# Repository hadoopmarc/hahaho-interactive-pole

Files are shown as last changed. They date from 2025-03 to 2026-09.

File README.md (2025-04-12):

# Hahaho Interactive Pole
The Interactive Pole is a standalone fun device that can be positioned in supervisioned public spaces. It features an activation button, various sensors, loudspeakers and several lighting and display options. The pole as displayed below originated from a project for the Amsterdam Police, carried out by one of the members of the Hahaho Foundation. 



The joined membership of the Hahaho Foundation feels that the remaining prototypes can serve for applications with a higher fun factor and we will use the interactive pole as a project in which people of all skill-levels can participate. If you live near Utrecht and want to see the pole in action, check our [website](https://hahaho-makers.nl/) for our biweekly meetings.

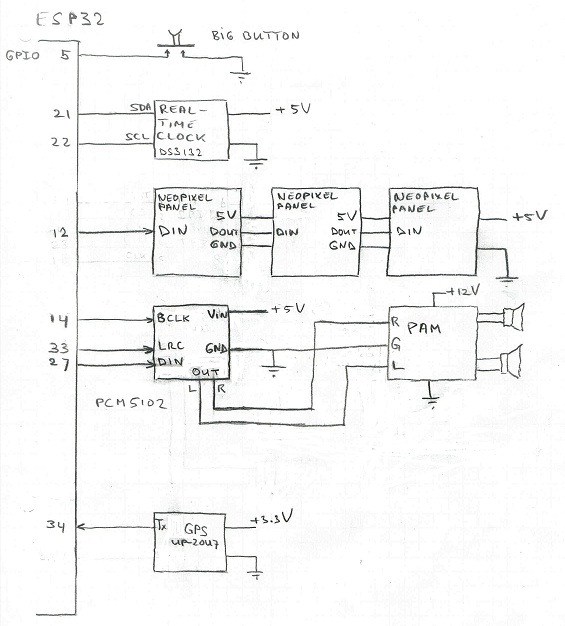
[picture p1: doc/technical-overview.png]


The figure above provides a schematic overview of the entire system (from the [detailed documentation](https://github.com/hadoopmarc/hahaho-interactive-pole/blob/main/inspiration/doc/HIP.pdf)). The table below shows the connections between the various components and the ESP32 dev board.

```c
//***************************************************************************************************
// Wiring.                                                                                          *
// ------------------------------------------------------------------------------------------------ *
// ESP32dev Signal  Connected to                Remarks                                             *
// -------- ------  --------------              ----------------------------------------------      *
// GPIO0    BOOT    Reserved bootloader         Also 2nd start button for test                      *
// GPIO1    TXD0    Reserved serial output                                                          *
// GPIO2            Built-in LED                                                                    *
// GPI03    RXD0    Reserved serial input                                                           *
// GPIO4            -                                                                               *
// GPIO5            Big button                  (active low)                                        *
// GPIO12           Neopixel panel DIN                                                              *
// GPIO14           I2S BCLK naar bijv. MAX98357A / PCM5102                                         *
// GPIO15           -                                                                               *
// GPIO16   RXD2    -                                                                               *
// GPIO17   TXD2    -                                                                               *
// GPIO18   SCK     -                                                                               *
// GPIO19   MISO    -                                                                               *
// GPIO21           SDA for I2C (DS3132)                                                            *
// GPIO22           SCK for I2C (DS3132)                                                            *
// GPIO23   MOSI    -                                                                               *
// GPIO25   -       audio output van interne DAC.                                                   *
// GPIO26   -       audio output van interne DAC.                                                   *
// GPIO27   -       I2S DIN  naar bijv. MAX98357A / PCM5102                                         *
// GPIO32   -       Enable VIN of PCM5102                                                           *
// GPIO33   -       I2S LRC  naar bijv. MAX98357A / PCM5102                                         *
// GPIO34   -       GPS TX                      (input only pin)                                    *
// GPIO35   -       -                           (input only pin)                                    *
// -------  ------  ----------------                                                                *
// GND      -       Power supply GND                                                                *
// VCC 5 V  -       Power supply                                                                    *
// VCC 5 V  -       Power supply                                                                    *
// 3.3 V    -       GPS Vcc                                                                         *
// EN       -       -                                                                               *
//***************************************************************************************************
```

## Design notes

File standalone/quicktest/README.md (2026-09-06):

## Intereractive Pole Quicktest

This is a useful small script that demonstrates the functionality of the Interactive Pole as of August 2026. Herman composed it using AI. These are the functionalities demonstrated:

 - sensing of the red button being pushed
 - sensing of passing people using the two PIR sensors
 - playing a sound file with the mp3-player
 - displaying a text on the Neopixel display
 - flashing the stroboscope light
 
 The functionalities it misses compared to the full firmware:
 
 - webserver with dashboard, serial monitor and OTA-updates
 - high level library to program the Interactive Pole without detailed knowledge of the sensors and actuators

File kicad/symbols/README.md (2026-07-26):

https://forum.kicad.info/t/esp32-dev-ch340-c-symbol-and-footprint/56483/13

See for elegant way to install 3rd party symbols and footprints: https://github.com/hadoopmarc/gps-controlled-lcd-shutter/blob/main/kicad/footprints/README.md

Something similar in win11 can be configured in:
C:\Users\marcd\Documents\KiCad\10.0\3rdparty
So, just put the .kicad_sym and .kicad_mod files in this directory.

Note that the system libraries are located at (after installing for all users):
C:\Program Files\KiCad\10.0\share\kicad

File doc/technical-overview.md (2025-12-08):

#technisch overzicht

Electronic parts
- ESP-WROOM-32
- [PCM5102A DAC module for Raspberry Pi](https://manuals.plus/asin/B07Q9K5MT8, also see for soldering bridges: https://github.com/pschatzmann/arduino-audio-tools/wiki/External-DAC)
- [PAM8610 2x15 W audio amplifier](https://nl.aliexpress.com/item/1005006493004179.html)
- 2 x loudspeaker 5W
- microswitch
- microphone
- [2 x HC-SR501 PIR sensor module](https://nl.aliexpress.com/item/1005006834678128.html or https://nl.aliexpress.com/item/1005006227628663.html)
- (GPS module Ublox Neo 6M)
- PCB, including 12V to 5V power supply
- 12V accu

Hardware parts:
- pole
- stand
- large button

Future actuators:
- LED's
- displays

Future sensors:
- lidar

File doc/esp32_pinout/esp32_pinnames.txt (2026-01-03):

The pinnames below are defined in src/libraries/h3ip_wiring/esp32_wiring.h

They are repeated below to allow for copy/paste to the pinout diagram.

Left column

reserved
ADC1_0
ADC1_3
frontPIR
backPIR
bclkI2S
lrcI2S
DAC1
DAC2
dinI2S
sckHSPI
misoHSPI
mosiHSPI

Right column

free
sclI2C
reserved
reserved
sdaI2C
stroboscope
neoPixel
redButton
mp3DFTX
mp3DFRX
buzzer
internalLED
csHSPI

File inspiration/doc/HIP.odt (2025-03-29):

HaHaHo Interactive Pole

# Inleiding.

Dit document beschrijft de ontwikkeling van de voorganger van de HaHaHo Interactive Pole. Het gaat hierbij om een paal met daarin een microprocessor.

# Hardware.

De hardware bestaat uit de paal met daarop een grote knop (type noodstop). In de paal bevindt zich een ESP32 processor, een versterker, een luidspreker waarop teksten kunnen worden uitgestuurd, twee Neopixel displays (voorzijde en achterzijde) met elk 4 panels van 8x8 Neopixels, een Real time clock en een GPS module.
De elektronica wordt gevoed vanuit een (oplaadbare) accu.

# Software.

De software voor de ESP32 is geschreven in C++. PlatformIO wordt gebruikt als ontwikkelsysteem.
De broncode van de software is vrij toegankelijk.
De software kan geconfigureerd worden d.m.v. een geïntegreerde webinterface. Via de webinterface is er toegang tot de loggegevens. De gegevens op het display zijn ook zichtbaar via de webinterface.

# User interfaces.

Op de voorkant van de paal is een display aanwezig. Er is gekozen voor 4 Neopixel panels van 65 x 65 mm. Deze is zichtbaar voor de passanten. Aan de achterzijde is ook een paneel voor de beambte. Hierop wordt het volgnummer gepresenteerd.

Na opstarten is het systeem gereed en kan het gebruikt worden. De GPS coördinaten van de plaats van de paal wordt gemeten indien er signaal van voldoende satellieten ontvangen kan worden. Zodra de coördinaten bekend zijn wordt dat getoond op de “home”-pagina van de webinterface.
De coördinaten worden opgeslagen in de registratie-file.

Bij opstarten toont het display in blauwe cijfers het IP-adres, waarmee toegang tot de webinterface kan worden verkregen. Dit gaat in 4 stappen, bijvoorbeeld “192”, “168”, “4”, “1”. In dit voorbeeld is het IP-adres 192.168.4.1.

In ruststand wordt op het display een patroon getoond om aan te geven dat de volgende passant geaccepteerd kan worden. Zodra er dan op de grote knop wordt gedrukt wordt krijgt de passant een reactie. Op het paneel aan de de achterzijde wordt het volgnummer getoond in rood of groen.
Tegelijkertijd klinkt uit de luidspreker in de paal de tekst zoals: “Spring drie keer in de lucht” of “Loop een rondje rond de paal”, al of niet voorafgegaan door het volgnummer. De gesproken teksten zijn beschikbaar in 2 talen (Nederlands en Engels). Er kan ingesteld worden welke taal of talen worden gebruikt en of het volgnummer al dan niet moet worden uitgesproken.

De gegevens van de passerende personen worden opgeslagen (alleen volgnummer en tijdstip) in registratiefiles. Om de hoeveelheid data te beperken worden de niet-geselecteerde personen niet geregistreerd. Dat zijn dus de ontbrekende volgnummers.

Er is een tweede user-interface beschikbaar via een WiFi verbinding. Daartoe wordt er op de ESP32 een AP (accesspoint) aangemaakt waarop kan worden ingelogd met een PC, tablet of telefoon. De naam van het accesspoint is “HIP-NET-xx”, waarbij “xx” een code is die bepaald wordt door het MAC adres van de ESP32. Dit maakt het mogelijk om met meer dan één paal vlak bij elkaar te werken. Het IP-adres wordt getoond bij opstarten van de ESP32. Ga met een willekeurige browser naar http://<IP-adres>/index.html.

# Webinterface.

## Hoofdscherm (Home).

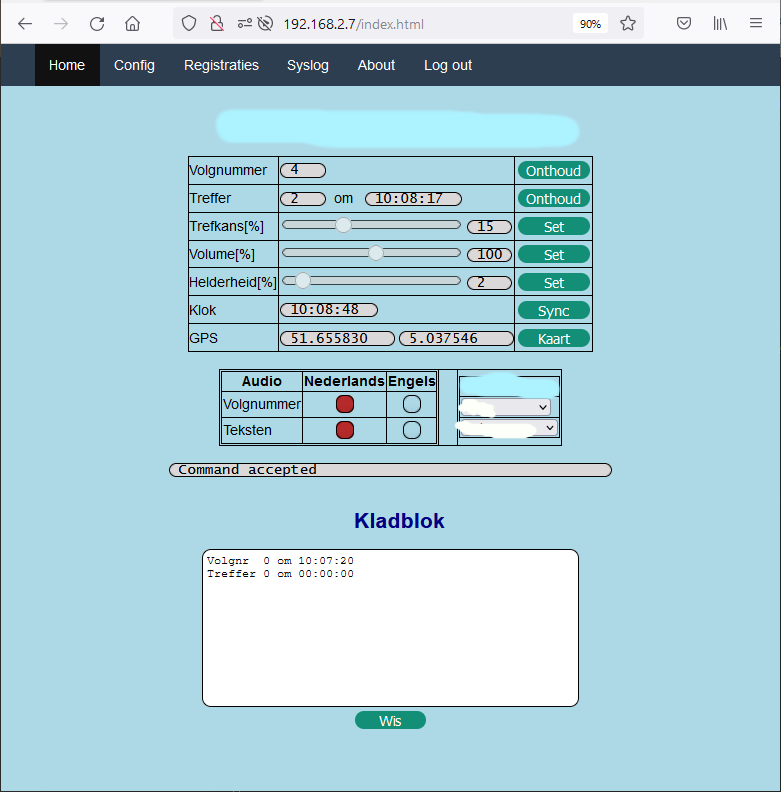
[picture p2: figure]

Het hoofdscherm toont het volgnummer en het nummer van de laatste “treffer”. Met de “Onthoud” knoppen kan een geheugensteuntje (volgnummer of treffer) in het kladblok onderaan het scherm worden gezet. De trefkans kan worden ingesteld met de schuifbalk, daarna op “Set” klikken. Op dezelfde manier kan het volume van de luidspreker en de helderheid van het display ingesteld worden met de daarbij behorende schuifbalken
De RTC clock kan worden gelijkgezet met de klok van de aangesloten PC/tablet/telefoon.
De GPS-regel toont de coördinaten van de huidige positie van de paal. Het kan even duren voordat er voldoende satellieten gedetecteerd zijn. Soms is dat onmogelijk en blijven de coördinaten leeg.

Met de knoppen in het “Audio”-blokje is te configureren welke teksten worden uitgesproken.

Met de “Kaart”-knop wordt die positie op een kaart aangegeven (indien er Internet verbinding is).

Verder kunnen de audio-instellingen worden gewijzigd en het model van de signalering (pijl of stoplicht). Omdat bij het pijl-model de uitgang voor niet geselecteerde mensen soms rechts en soms links is, kan links en rechts worden omgewisseld. Kies voor “Rechts uit” of “Links uit”.

## Configuratiescherm (Config).

Hierin kunnen wat configuratie parameters opgeslagen worden. Het scherm is alleen toegankelijk voor de “admin” user.
Het scherm ziet er als volgt uit:

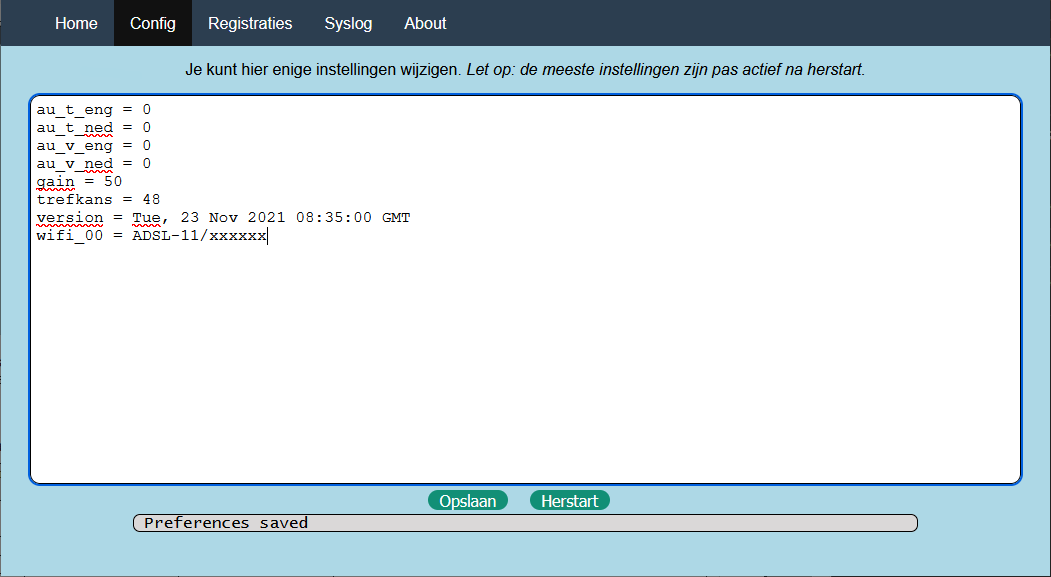
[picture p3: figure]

Na het aanpassen van de mogelijke instellingen moet er op “Opslaan” worden gedrukt. De instellingen hebben veelal pas effect na een herstart, daarom is er ook een “Herstart” -knop aanwezig.

### Configuratie parameters.

De volgende parameters kunnen worden ingesteld in het configuratiescherm.

Parameter naam | Voorbeeld parameter | Default | Beschrijving
trefkans | 50 | 20 | Trefkans in procenten. 20 procent is een kans van 1 op 5.
userpw | H7Ft20? | bloemkool | Het password voor normale toegang.
adminpw | BLT66.. | supernova | Het password voor admin user met extra rechten.
wifipw | hkp32x4 | Gelijk aan netwerk naam. | Het password voor de WiFi verbinding. Bijvboorbeeld “VGW-NET-CE”.
au_v_ned | 0 | 1 | Audio aan/uit voor Nederlands volgnummer.
au_t_ned | 0 | 1 | Audio aan/uit voor Nederlandse tekst.
au_v_eng | 0 | 1 | Audio aan/uit voor Engels volgnummer.
au_t_eng | 0 | 1 | Audio aan/uit voor Engelse tekst.
gain | 66 | 50 | Audio output niveau 0..100 procent
wifi_00 | ZIGGO_V22/passwd | | WiFi netwerk en password voor “station”-toegang.
wifi_01 | ZIGGO_V33/passwd | | Tweede WiFi netwerk en password voor “station”-toegang.
brightness | 20 | 30 | Helderheid Neopixel panels 0..255.
model | Matrix image | pijl | Display model 1
lrrev | Matrix image | rechts | Display model 2

De groen gekleurde parameters zijn ook via de home page van de web interface instelbaar.

De WiFi instellingen zijn vooral handig tijdens het ontwikkelen en testen van de software. Je kunt dan via het WiFi accesspoint van het interne WiFi net toegang krijgen tot de ESP32. Bij een reset wordt namelijk het interne WiFi accesspoint van de ESP32 uitgeschakeld, waardoor je steeds opnieuw moet inloggen op het accesspoint.

De 2 passwords moeten zo snel mogelijk aangepast worden.

Indien toegang niet meer mogelijk is, dan is een reset van de 3 passwords mogelijk door tijdens het opstarten (terwijl het IP-adres getoond wordt) de grote knop continue in te drukken. Daarna wachten tot het systeem gereed is (de pijlen worden getoond), dan opnieuw opstarten zonder op de knop te drukken.
Vergeet niet de passwords weer in te stellen.

## Registratiescherm.

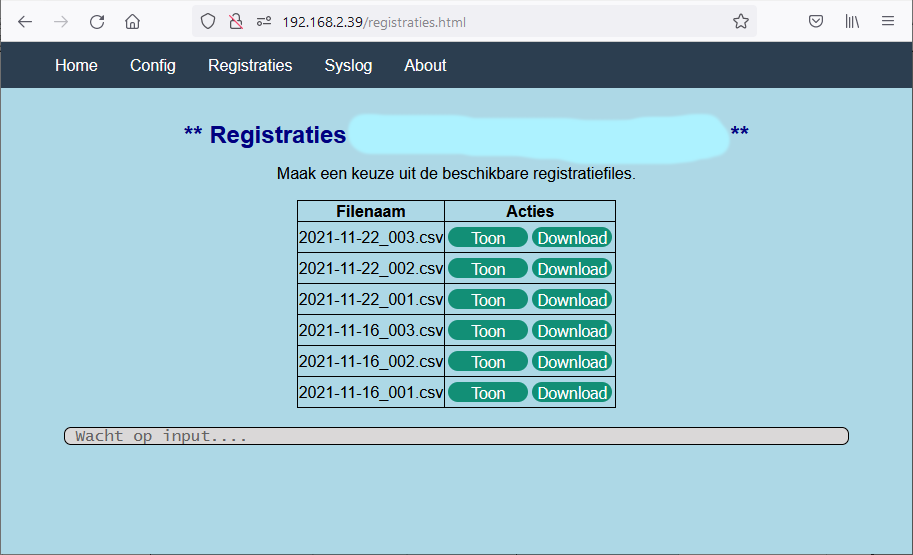
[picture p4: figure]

Alle in het filesysteem aanwezige registratiefiles worden getoond. De laatste aangemaakte registratiefile staat bovenaan. Met de “Toon” knop kan deze worden ingezien. Met de “Download” knop kan de betreffende file opgeslagen worden of direct geopend worden in bijvoorbeeld Excel.

Een beschrijving van de registratiefiles staat in hoofdstuk 7.

## Syslogscherm.

Dit scherm toont debug informatie Het wordt alleen gebruikt tijden ontwikkelen en testen van de software. Het scherm is alleen toegankelijk voor de “admin”-user.

## Aboutscherm.

Dit scherm geeft wat info over het systeem.

# Schematisch overzicht.


//***************************************************************************************************

// Wiring. *

// ------------------------------------------------------------------------------------------------ *

// ESP32dev Signal Connected to Remarks *

// -------- ------ -------------- ---------------------------------------------- *

// GPIO0 BOOT Reserved bootloader Also 2nd start button for test *

// GPIO1 TXD0 Reserved serial output *

// GPIO2 Built-in LED *

// GPI03 RXD0 Reserved serial input *

// GPIO4 - *

// GPIO5 Big button (active low) *

// GPIO12 Neopixel panel DIN *

// GPIO14 I2S BCLK naar bijv. MAX98357A / PCM5102 *

// GPIO15 - *

// GPIO16 RXD2 - *

// GPIO17 TXD2 - *

// GPIO18 SCK - *

// GPIO19 MISO - *

// GPIO21 SDA for I2C (DS3132) *

// GPIO22 SCK for I2C (DS3132) *

// GPIO23 MOSI - *

// GPIO25 - audio output van interne DAC. *

// GPIO26 - audio output van interne DAC. *

// GPIO27 - I2S DIN naar bijv. MAX98357A / PCM5102 *

// GPIO32 - Enable VIN of PCM5102 *

// GPIO33 - I2S LRC naar bijv. MAX98357A / PCM5102 *

// GPIO34 - GPS TX (input only pin) *

// GPIO35 - - (input only pin) *

// ------- ------ ---------------- *

// GND - Power supply GND *

// VCC 5 V - Power supply *

// VCC 5 V - Power supply *

// 3.3 V - GPS Vcc *

// EN - - *

//***************************************************************************************************

# Registratiefiles.

Als er na een druk op de knop een selectie heeft plaatsgevonden, dan wordt dat geregistreerd in een file. De registratiefiles worden opgeslagen in het flash-geheugen van de ESP32 in de SPIFFS partitie. De naam van een registratiefile ziet er bijvoorbeeld zo uit:

2021-11-01_001.csv

Het eerste gedeelte van de filenaam is de datum van aanmaak in de vorm “YYYY-MM-DD”. Het tweede gedeelte is een volgnummer voor het geval er meer dan één file op de dag aangemaakt wordt.
Als er te weinig ruimte aanwezig is in het filesysteem, dan worden de oudste files verwijderd.

## Registratiefile structuur.

Een registratiefile bestaat uit een aantal records. Records worden van elkaar gescheiden door een newline. Velden in een record worden van elkaar gescheiden door een komma. Een registratiefile is hiermee geschikt om ingelezen te worden in bijvoorbeeld Excel.

Er zijn 3 record types:

Type | Omschrijving
P | Ingestelde trefkans in procent (probability).
G | GPS locatie. Bevat datum (DD-MM-JJJJ) en de GPS coördinaten.
H | Volgnummer en tijdstip van een geselecteerde persoon.

Het “G” record komt slechts één keer voor aan het begin van de file.
Het “P” record staat ook altijd aan het begin. Indien de trefkans wordt gewijzigd volgt er een extra “P”-record.

Voorbeeld van de inhoud van een registratiefile:

G,01-11-2021,51.655863,5.037566

P,50

H,6,17:25:34

H,7,17:26:07

H,9,17:26:13

H,10,17:30:51

H,11,17:30:53

H,17,17:31:02

H,18,17:31:13

H,19,17:31:15

H,22,17:31:19

H,25,17:31:24

H,27,17:31:32

…

Er werd hier dus gewerkt op 1 november 2021 op locatie 51.655863, 5.037566 met een trefkans van 50 procent. De eerste selectie was om 17:25:34.

# Characterset 8x8 display.

Op de 8x8 Neopixel displays kan een beperkt aantal tekens worden weergegeven.
Dat zijn de cijfers 0 t/m 9, een “V”, een “X”, een “>” en een “<”. De vormgeving is als volgt:

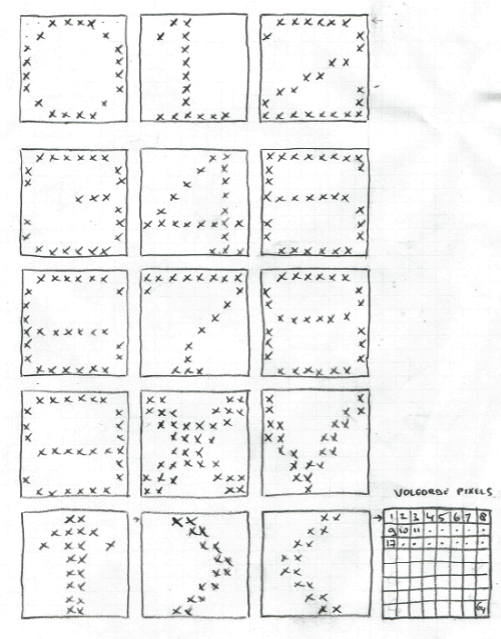
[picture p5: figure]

Het eerste pixel p het paneel is linksboven, volgende pixel is degene daar rechts van. Dan rij afmaken en dan naar de volgende rijen. Dus van links naar rechts en van boven naar beneden. Dit geldt voor de 66 x 66 mm modules.

De tekens worden weergegeven op 4 panelen, verticaal. Elk teken wordt gevolgd door 2 onverlichte rijen. Voor de pijl naar beneden en de drukknop zijn speciale tekens gemaakt.

HIP -- pagina 7

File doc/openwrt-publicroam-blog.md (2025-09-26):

# A Raspberry Pi travel router for publicroam.nl

The [Makey Mondays in Utrecht](https://www.meetup.com/hahaho-sharingtechnology-innovative-tech-meetings/events/?type=past),
The Netherlands, have a special requirement
on the use of the [publicroam.nl](https://publicroam.nl/en/) Wi-Fi network.
Participants should be able to connect to the internet through publicroam.nl and at
the same time be able to perform OTA (over the air) firmware upgrades to simple
microcontrollers like the
[ESP32](https://www.espressif.com/en/products/socs/esp32). However, it is not easy to
make such microcontrollers connect with publicroam.nl, because it requires
authentication with the
[PEAP/EAP-MSCHAPV2 protocol](https://en.wikipedia.org/wiki/Protected_Extensible_Authentication_Protocol). This
protocol on its turn requires several libraries that take a lot of
the scarce resources of a simple microcontroller. Therefore, it is more
attractive to use an additional wireless router that connects to publicroam.nl and
serves as a simple secure Wi-Fi access point with a second radio, see
the figure below. This blog post details how this was realized using an old
[Raspberry Pi](https://www.raspberrypi.com/) configured with
[OpenWrt](https://openwrt.org/) routing firmware.

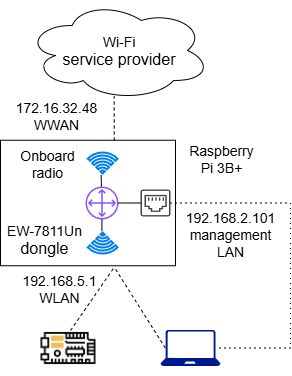
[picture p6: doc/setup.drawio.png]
Connection diagram


It can be noted that this setup is identical to that of a travel router, which is
often used to act as a protective shield when using untrusted hotel Wi-Fi networks.
In fact, OpenWRT has the `Travelmate` extension package to easily make available
known configurations to public Wi-Fi service providers. However, the publicroam.nl
configuration does not seem to easily fit in this framework, as I could not find
any references to it. Therefore, the exploration towards the proper configuration
for publicroam.nl was done without `Travelmate`.

Looking back, the main hurdle encountered was to give the OpenWrt `wpad` package
access to the [publicroam.nl certificate](https://publicroam.nl/certificate-latest)
for the IEEE 802.1x authentication that is part of the MSCHAPV2 protocol. The [LuCI
webui](https://openwrt.org/docs/guide-user/luci/start) to OpenWrt suggests that
uploading the certificate with LuCI should suffice, but this turned out to fail.
This was followed by a number of random attempts with different versions of the
`wpad` package and different ways to install the certificate, until I hit upon
a working configuration. Because of my limited knowledge of OpenWrt, linux and
certificate chains, I have not tried to simplify the resulting configuration or
pinpoint any issues in OpenWrt. I figured, though, that the literal documentation
of the resulting configuration could be of help to other users and here it is!

Without detailing steps documented elsewhere, the setup described can be
realized as follows:
- be sure that you use a solid 5V/3A power supply for the RPi, because the power
drawn by an additional radio can easily result in brownout situations (RPi gets
in a reboot loop). To be on the safe side, radio transmit power in the configurations
below is limited to 10 mW
- burn the OpenWrt firmware on the RPi's SD-card as described
[here](https://openwrt.org/toh/raspberry_pi_foundation/raspberry_pi)
- get [SSH access to OpenWrt](https://openwrt.org/docs/guide-quick-start/sshadministration)
from your laptop
- using LuCI temporarily connect to your private Wi-Fi network for internet access
- using LuCI install the following OpenWrt pacakages: ca-bundle, kmod-rtl8192cu,
openssh-sftp-server, openssl-util, rtl8192cu-firmware, wpa-cli, wpad-openssl
- insert a Wi-Fi USB dongle as a second radio (the rtl8192cu packages installed
above are required for the prevalent EW-7811Un dongle)
- copy the config files detailed below to /etc/config, e.g. using winscp (after
editing credentials and network names)
- copy the downloaded
[publicroam Wi-Fi certificate](https://publicroam.nl/certificate-latest) to /etc/ssl/certs
- get a terminal in the RPi with ssh or Putty and run the command `openssl rehash`
- reboot the RPi and you should be able to connect to the configured SSID using
the configured password. In a publicroam environment the system logs in LuCI should
indicate a valid connection to publicroam (see the end of this post for example
logs).

Hardware: Raspberry Pi 3B+ with EW-7811Un from Edimax \
Firmware: openwrt-24.10.2-bcm27xx-bcm2710-rpi-3-squashfs-sysupgrade.img.gz

/etc/config/network
```
config interface 'loopback'
	option device 'lo'
	option proto 'static'
	option ipaddr '127.0.0.1'
	option netmask '255.0.0.0'

config device
	option name 'br-lan'
	option type 'bridge'
	list ports 'eth0'

config interface 'lan'
	option device 'br-lan'
	option proto 'dhcp'

config interface 'wlan_hahaho'
	option proto 'static'
	option ipaddr '192.168.5.1'
	option netmask '255.255.255.0'
	option device 'phy0-ap0'

config interface 'wwan_pubroam'
	option proto 'dhcp'
	option device 'radio0.network1'
```
 /etc/config/wireless
```
config wifi-device 'radio0'
	option type 'mac80211'
	option path 'platform/soc/3f300000.mmcnr/mmc_host/mmc1/mmc1:0001/mmc1:0001:1'
	option channel 'auto'
	option band '5g'
	option htmode 'VHT20'
	option cell_density '0'
	option log_level '0'
	option txpower '10'

config wifi-iface 'default_radio0'
	option device 'radio0'
	option mode 'sta'
	option encryption 'wpa2'
	option network 'wwan_pubroam'
	option ssid 'publicroam'
	option log_level '0'
	option eap_type 'peap'
	option auth 'EAP-MSCHAPV2'
	option identity 'publicroam-username'
	option password 'publicroam-password'
	option anonymous_identity 'anonymous'
	option ieee80211w '1'
	option ca_cert_usesystem '1'

config wifi-device 'radio1'
	option type 'mac80211'
	option path 'platform/soc/3f980000.usb/usb1/1-1/1-1.2/1-1.2:1.0'
	option channel '9'
	option band '2g'
	option htmode 'HT20'
	option cell_density '0'
	option log_level '1'
	option txpower '10'

config wifi-iface 'default_radio1'
	option device 'radio1'
	option mode 'ap'
	option ssid 'offered-wifi-ssid'
	option key 'offered-wifi-password'
	option encryption 'psk2'
	option network 'wlan_hahaho'
	option log_level '1'
```

/etc/config/firewall
```
config defaults
	option input 'REJECT'
	option output 'ACCEPT'
	option forward 'REJECT'

config zone
	option name 'lan'
	option input 'ACCEPT'
	option output 'ACCEPT'
	option forward 'ACCEPT'
	list network 'lan'
	option masq '1'

config zone
	option name 'lan_wlan'
	option input 'ACCEPT'
	option output 'ACCEPT'
	option forward 'ACCEPT'
	list network 'wlan_hahaho'
	option masq '1'

config forwarding
	option src 'lan_wlan'
	option dest 'lan'

config zone
	option name 'wwan_pubr'
	option input 'ACCEPT'
	option output 'ACCEPT'
	option forward 'ACCEPT'
	list network 'wwan_pubroam'
	option masq '1'

config forwarding
	option src 'lan_wlan'
	option dest 'wwan_pubr'

config forwarding
	option src 'wwan_pubr'
	option dest 'lan_wlan'
```

/etc/config/dhcp
```
config dnsmasq
	option domainneeded '1'
	option localise_queries '1'
	option rebind_protection '1'
	option rebind_localhost '1'
	option local '/lan/'
	option domain 'lan'
	option expandhosts '1'
	option cachesize '1000'
	option authoritative '1'
	option readethers '1'
	option leasefile '/tmp/dhcp.leases'
	option resolvfile '/tmp/resolv.conf.d/resolv.conf.auto'
	option localservice '1'
	option ednspacket_max '1232'
	list interface 'wlan_hahaho'
	list notinterface 'lan'

config dhcp 'lan'
	option interface 'lan'
	option start '100'
	option limit '150'
	option leasetime '12h'
	option dhcpv4 'server'
	option dhcpv6 'hybrid'
	option ra 'hybrid'
	list ra_flags 'managed-config'
	list ra_flags 'other-config'
	option ignore '1'

config dhcp 'wan'
	option interface 'wan'
	option ignore '1'

config odhcpd 'odhcpd'
	option maindhcp '0'
	option leasefile '/tmp/hosts/odhcpd'
	option leasetrigger '/usr/sbin/odhcpd-update'
	option loglevel '4'

config dhcp 'wlan_hahaho'
	option interface 'wlan_hahaho'
	option start '100'
	option limit '150'
	option leasetime '12h'
	option force '1'
```

Syslogs related to establishing the wireless interfaces
```
Sat Sep  6 14:51:18 2025 daemon.notice netifd: Interface 'wlan_hahaho' is enabled
Sat Sep  6 14:51:18 2025 daemon.notice netifd: Interface 'wlan_hahaho' is setting up now
Sat Sep  6 14:51:18 2025 daemon.notice wpa_supplicant[814]: phy1-sta0: Trying to associate with 34:85:84:4e:e7:a5 (SSID='publicroam' freq=5220 MHz)
Sat Sep  6 14:51:18 2025 daemon.notice netifd: Interface 'wlan_hahaho' is now up
Sat Sep  6 14:51:18 2025 kern.info kernel: [   14.595441] rtl8192cu: MAC auto ON okay!
Sat Sep  6 14:51:19 2025 kern.info kernel: [   14.643075] rtl8192cu: Tx queue select: 0x05
Sat Sep  6 14:51:19 2025 user.notice firewall: Reloading firewall due to ifup of wlan_hahaho (phy0-ap0)
Sat Sep  6 14:51:20 2025 daemon.notice netifd: Network device 'phy0-ap0' link is up
Sat Sep  6 14:51:20 2025 daemon.notice netifd: Interface 'wlan_hahaho' has link connectivity
Sat Sep  6 14:51:20 2025 kern.info kernel: [   16.118173] IPv6: ADDRCONF(NETDEV_CHANGE): phy0-ap0: link becomes ready
Sat Sep  6 14:51:20 2025 daemon.notice netifd: Network device 'phy1-sta0' link is up
Sat Sep  6 14:51:20 2025 daemon.notice netifd: Interface 'wwan_pubroam' has link connectivity
Sat Sep  6 14:51:20 2025 daemon.notice netifd: Interface 'wwan_pubroam' is setting up now
Sat Sep  6 14:51:20 2025 daemon.notice wpa_supplicant[814]: phy1-sta0: Associated with 34:85:84:4e:e7:a5
Sat Sep  6 14:51:20 2025 daemon.notice wpa_supplicant[814]: phy1-sta0: CTRL-EVENT-EAP-STARTED EAP authentication started
Sat Sep  6 14:51:20 2025 daemon.notice wpa_supplicant[814]: phy1-sta0: CTRL-EVENT-SUBNET-STATUS-UPDATE status=0
Sat Sep  6 14:51:20 2025 daemon.notice wpa_supplicant[814]: phy1-sta0: CTRL-EVENT-EAP-PROPOSED-METHOD vendor=0 method=25
Sat Sep  6 14:51:20 2025 daemon.notice netifd: wwan_pubroam (1981): udhcpc: started, v1.36.1
Sat Sep  6 14:51:20 2025 daemon.notice hostapd: phy0-ap0: interface state UNINITIALIZED->ENABLED
Sat Sep  6 14:51:20 2025 daemon.notice hostapd: phy0-ap0: AP-ENABLED
Sat Sep  6 14:51:20 2025 daemon.notice netifd: wwan_pubroam (1981): udhcpc: broadcasting discover
Sat Sep  6 14:51:20 2025 daemon.info dnsmasq[1]: exiting on receipt of SIGTERM
Sat Sep  6 14:51:21 2025 daemon.notice wpa_supplicant[814]: phy1-sta0: CTRL-EVENT-EAP-METHOD EAP vendor 0 method 25 (PEAP) selected
Sat Sep  6 14:51:21 2025 daemon.notice wpa_supplicant[814]: phy1-sta0: CTRL-EVENT-EAP-PEER-CERT depth=2 subject='/C=US/ST=New Jersey/L=Jersey City/O=The USERTRUST Network/CN=USERTrust RSA Certification Authority' hash=e793c9b02fd8aa13e21c31228accb08119643b749c898964b1746d46c3d4cbd2
Sat Sep  6 14:51:21 2025 daemon.notice wpa_supplicant[814]: phy1-sta0: CTRL-EVENT-EAP-PEER-CERT depth=1 subject='/C=GB/ST=Greater Manchester/L=Salford/O=Sectigo Limited/CN=Sectigo RSA Extended Validation Secure Server CA' hash=57d8bdcd58955a5590a57c6aafa581ed9b96bed76fafee969b139187c5a872c7
Sat Sep  6 14:51:21 2025 daemon.notice wpa_supplicant[814]: phy1-sta0: CTRL-EVENT-EAP-PEER-CERT depth=0 subject='/serialNumber=70318433/jurisdictionC=NL/businessCategory=Private Organization/C=NL/ST=Utrecht/O=Publicroam B.V./CN=publicroam.nl' hash=64459d5bf4f035bb004e980e79780af84c6cb09fef64a95070dd25f247a9e276
Sat Sep  6 14:51:21 2025 daemon.notice wpa_supplicant[814]: phy1-sta0: CTRL-EVENT-EAP-PEER-ALT depth=0 DNS:publicroam.nl
Sat Sep  6 14:51:21 2025 daemon.notice wpa_supplicant[814]: phy1-sta0: CTRL-EVENT-EAP-PEER-ALT depth=0 DNS:www.publicroam.nl
Sat Sep  6 14:51:21 2025 daemon.notice netifd: Wireless device 'radio1' is now up
Sat Sep  6 14:51:21 2025 daemon.notice wpa_supplicant[814]: EAP-MSCHAPV2: Authentication succeeded
Sat Sep  6 14:51:21 2025 daemon.notice wpa_supplicant[814]: EAP-TLV: TLV Result - Success - EAP-TLV/Phase2 Completed
Sat Sep  6 14:51:21 2025 daemon.notice wpa_supplicant[814]: phy1-sta0: CTRL-EVENT-EAP-SUCCESS EAP authentication completed successfully
Sat Sep  6 14:51:21 2025 daemon.notice wpa_supplicant[814]: phy1-sta0: PMKSA-CACHE-ADDED 34:85:84:4e:e7:a5 0
Sat Sep  6 14:51:21 2025 daemon.notice wpa_supplicant[814]: phy1-sta0: WPA: Key negotiation completed with 34:85:84:4e:e7:a5 [PTK=CCMP GTK=CCMP]
Sat Sep  6 14:51:21 2025 daemon.notice wpa_supplicant[814]: phy1-sta0: CTRL-EVENT-CONNECTED - Connection to 34:85:84:4e:e7:a5 completed [id=0 id_str=]
Sat Sep  6 14:51:21 2025 kern.info kernel: [   16.922658] IPv6: ADDRCONF(NETDEV_CHANGE): phy1-sta0: link becomes ready
Sat Sep  6 14:51:21 2025 daemon.info dnsmasq[1]: started, version 2.90 cachesize 1000
Sat Sep  6 14:51:21 2025 daemon.info dnsmasq[1]: compile time options: IPv6 GNU-getopt no-DBus UBus no-i18n no-IDN DHCP no-DHCPv6 no-Lua TFTP no-conntrack no-ipset no-nftset no-auth no-cryptohash no-DNSSEC no-ID loop-detect inotify dumpfile
Sat Sep  6 14:51:21 2025 daemon.info dnsmasq[1]: UBus support enabled: connected to system bus
Sat Sep  6 14:51:21 2025 daemon.info dnsmasq-dhcp[1]: DHCP, IP range 192.168.5.100 -- 192.168.5.249, lease time 12h
Sat Sep  6 14:51:21 2025 daemon.info dnsmasq-dhcp[1]: DHCP, sockets bound exclusively to interface phy0-ap0
Sat Sep  6 14:51:21 2025 daemon.info dnsmasq[1]: using only locally-known addresses for test
Sat Sep  6 14:51:21 2025 daemon.info dnsmasq[1]: using only locally-known addresses for onion
Sat Sep  6 14:51:21 2025 daemon.info dnsmasq[1]: using only locally-known addresses for localhost
Sat Sep  6 14:51:21 2025 daemon.info dnsmasq[1]: using only locally-known addresses for local
Sat Sep  6 14:51:21 2025 daemon.info dnsmasq[1]: using only locally-known addresses for invalid
Sat Sep  6 14:51:21 2025 daemon.info dnsmasq[1]: using only locally-known addresses for bind
Sat Sep  6 14:51:21 2025 daemon.info dnsmasq[1]: using only locally-known addresses for lan
Sat Sep  6 14:51:21 2025 daemon.warn dnsmasq[1]: no servers found in /tmp/resolv.conf.d/resolv.conf.auto, will retry
Sat Sep  6 14:51:21 2025 daemon.info dnsmasq[1]: read /etc/hosts - 12 names
Sat Sep  6 14:51:21 2025 daemon.info dnsmasq[1]: read /tmp/hosts/dhcp.cfg01411c - 2 names
Sat Sep  6 14:51:21 2025 daemon.info dnsmasq-dhcp[1]: read /etc/ethers - 0 addresses
Sat Sep  6 14:51:24 2025 daemon.notice netifd: wwan_pubroam (1981): udhcpc: broadcasting discover
Sat Sep  6 14:51:25 2025 daemon.notice netifd: wwan_pubroam (1981): udhcpc: broadcasting select for 172.30.0.100, server 172.30.0.1
Sat Sep  6 14:51:25 2025 daemon.notice netifd: wwan_pubroam (1981): udhcpc: lease of 172.30.0.100 obtained from 172.30.0.1, lease time 3600
Sat Sep  6 14:51:25 2025 daemon.notice netifd: Interface 'wwan_pubroam' is now up
```

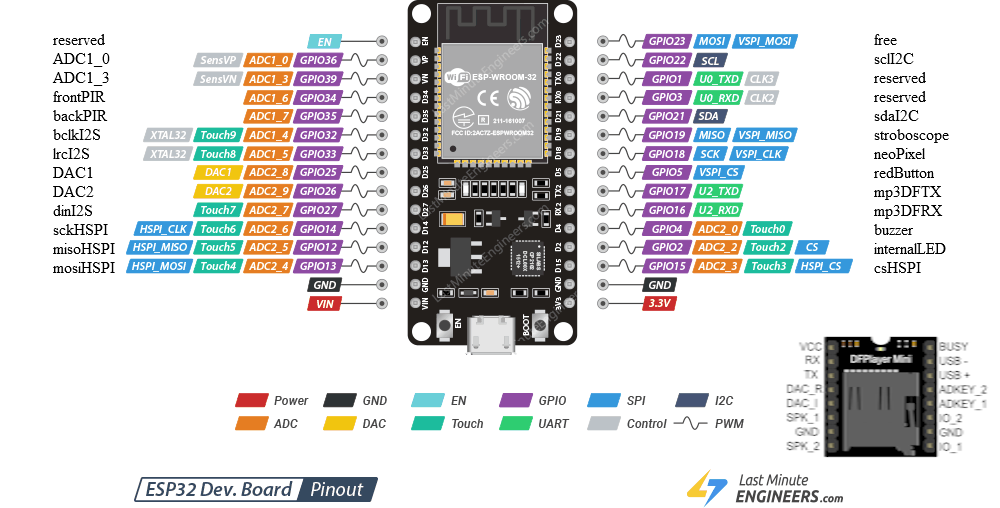
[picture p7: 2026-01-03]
doc/esp32_pinout/esp32_pinout.png

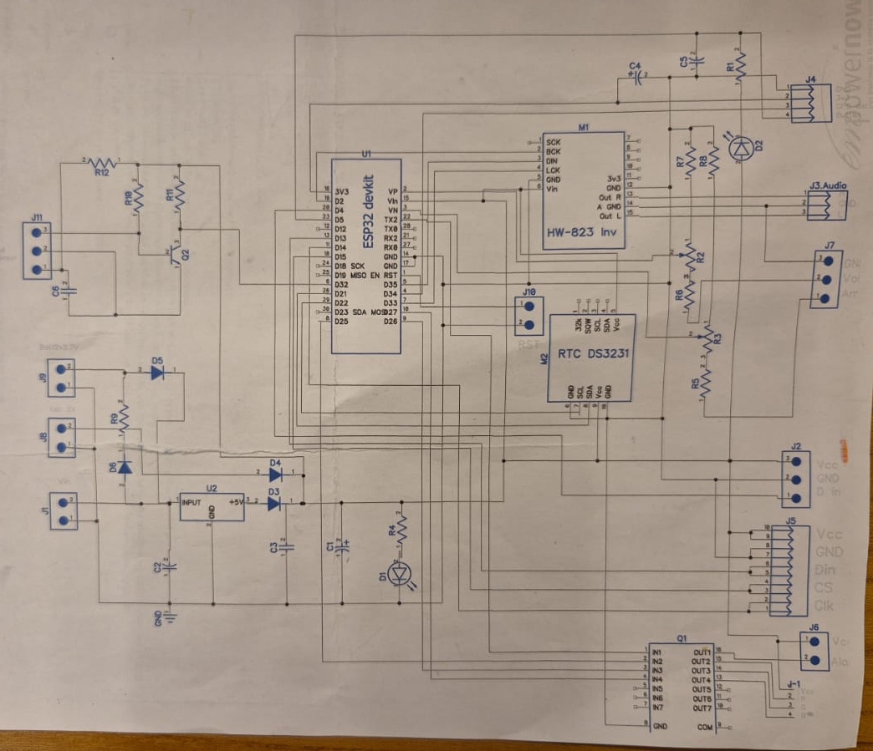
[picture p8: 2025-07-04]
doc/circuit-interactive-pole-handdrawn.jpg

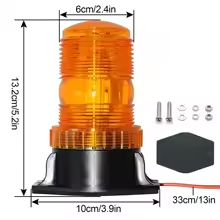
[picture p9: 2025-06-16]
doc/stroboscope-light.png

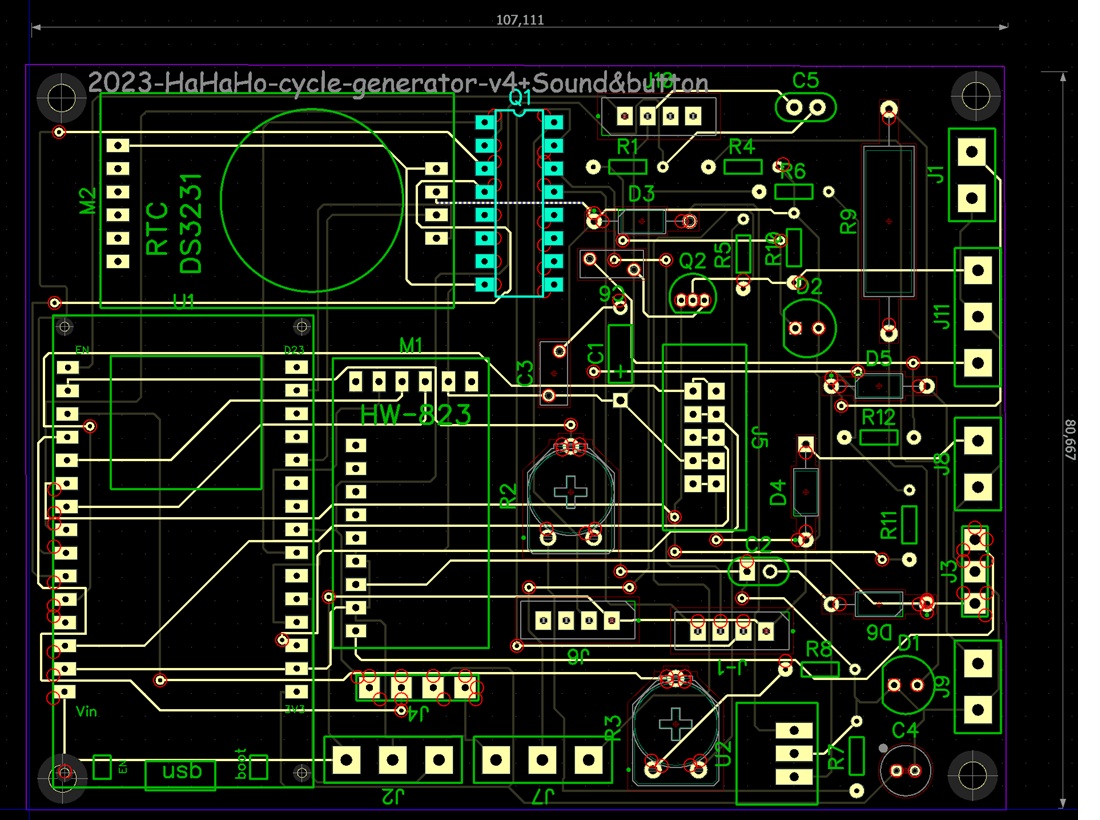
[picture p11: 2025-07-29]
doc/PCB-interactive-pole.jpg

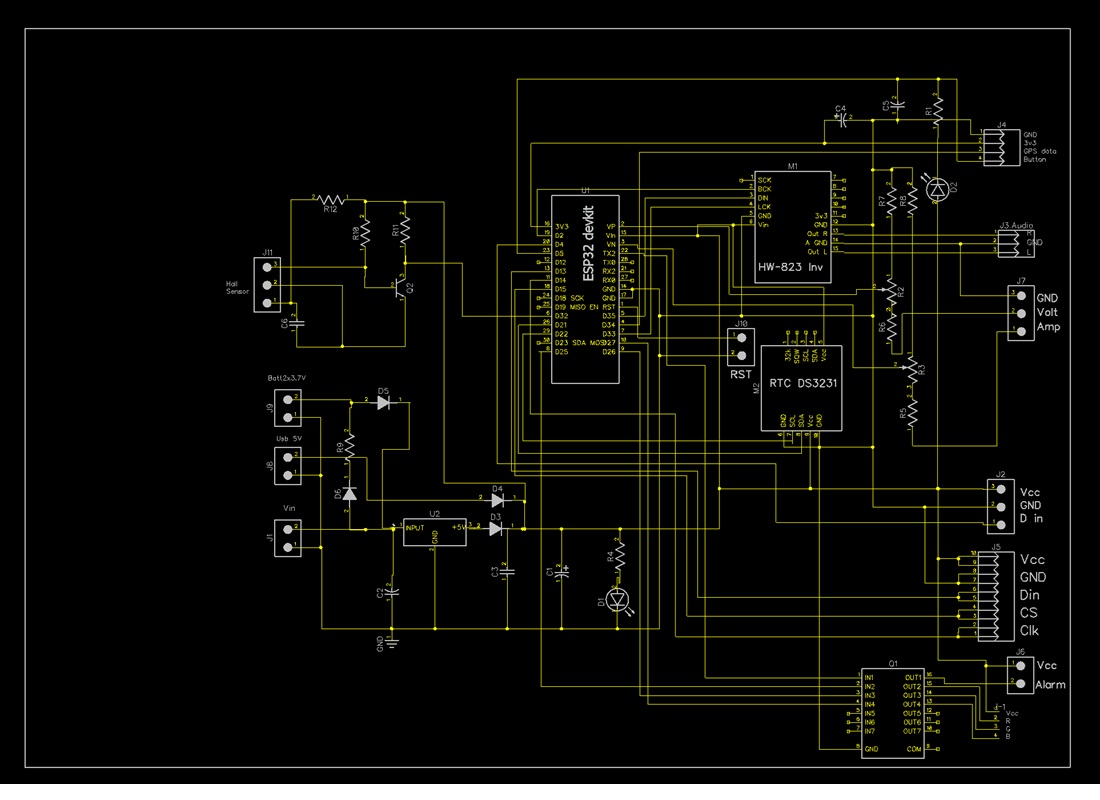
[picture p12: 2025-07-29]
doc/circuit-interactive-pole-digidrawn.jpg

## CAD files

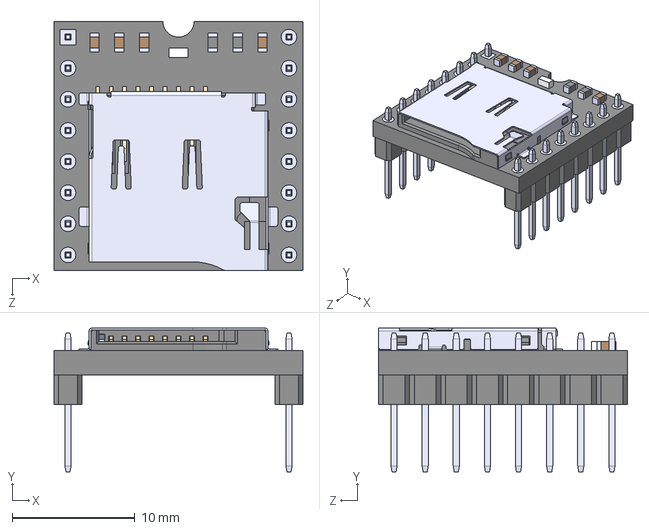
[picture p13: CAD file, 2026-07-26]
kicad/symbols/DFR0299/DFR0299.step
20.3 x 11.8 x 20.3 mm

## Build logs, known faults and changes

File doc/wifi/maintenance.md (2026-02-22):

# HaHaHo access point
The RPI3 based HaHaHo access point connects to the publicroam WiFi and offers
simple SSID + password WiFi access to microcontrollers, laptops, tablets and phones.
This writeup gives some background useful if it stops working some day.

## Hardware inspection

- the RPi3 should have a solid 5V 4A power supply (the additional radio draws a lot of power)
- the radio1 USB slot should contain an Edimax EW-7811Un WiFi dongle. This slot sits bottom
  right with respect to the ethernet port.

## System log inspection

If the access point does not show a visible HaHaHo SSID, the most certain way to get access
is to connect it to a LAN with an ethernet cable. The RPI3 will receive an IP address on this
LAN and with this address one can access the LuCI web interface, which contains the system log.

On linux or wsl one can find the IP address on the LAN using:

sudo nmap -sL 192.168.2.0/24

Look for an output line:

Nmap scan report for OpenWrt.your.domain (192.168.2.123)

## Renewing the publicroam certificate

For authentication towards publicroam, OpenWRT needs a valid certificate. This certificate is
renewed every year and for now, we do the renewal on the RPi manually. Connect with putty/ssh
and use the following commands (this assumes that openssl-util are installed in OpenWRT via
the LuCI web interface):

cd /tmp
wget https://publicroam.nl/certificate-latest
openssl x509 -inform der -in pr-nl6.cer -out pr-nl6.pem
mv pr-nl6.pem /etc/ssl/certs/

Automating this would only be useful if publicroam uses overlapping validity periods for their
radius server certificates and if the HaHaHo access point is powered up every meeting.

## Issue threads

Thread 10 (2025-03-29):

Standalone web UI on ESP32 with Arduino IDE

hadoopmarc, 2025-03-29:
First get a simple webUI working standalone on an ESP32 using the Arduino IDE. Later we will fit it into the total design (separate issue). Start from the template in https://github.com/hadoopmarc/hahaho-interactive-pole/tree/main/standalone/control/web_ui.

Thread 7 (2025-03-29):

Standalone Big Button on ESP32 with Arduino IDE

hadoopmarc, 2025-03-29:
First get the Big Red Button working standalone on an ESP32 using the Arduino IDE. Then we will fit it into the total design with PlatformIO (separate issue). Start from the template in https://github.com/hadoopmarc/hahaho-interactive-pole/tree/main/standalone/sense/PIR_sensor .

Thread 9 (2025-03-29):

Standalone NeoPixel display on ESP32 with Aduino IDE

hadoopmarc, 2025-03-29:
First get the NeoPixel matric LED display working standalone on an ESP32 using the Arduino IDE. Use a breadboard to connect an ESP32 module to the NeoPixel display. Later we will fit it into the total design with PlatformIO (separate issue). Start from the template in https://github.com/hadoopmarc/hahaho-interactive-pole/tree/main/standalone/actuate/neo_pixel.

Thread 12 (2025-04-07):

Standalone IR range sensor for ESP32 with Arduino IDE

hadoopmarc, 2025-04-07:
LD2410C 24 GHz Human Presence Sensor
High Accuracy Wave Radar Induction Module Body Heartbeat Detection Sensors

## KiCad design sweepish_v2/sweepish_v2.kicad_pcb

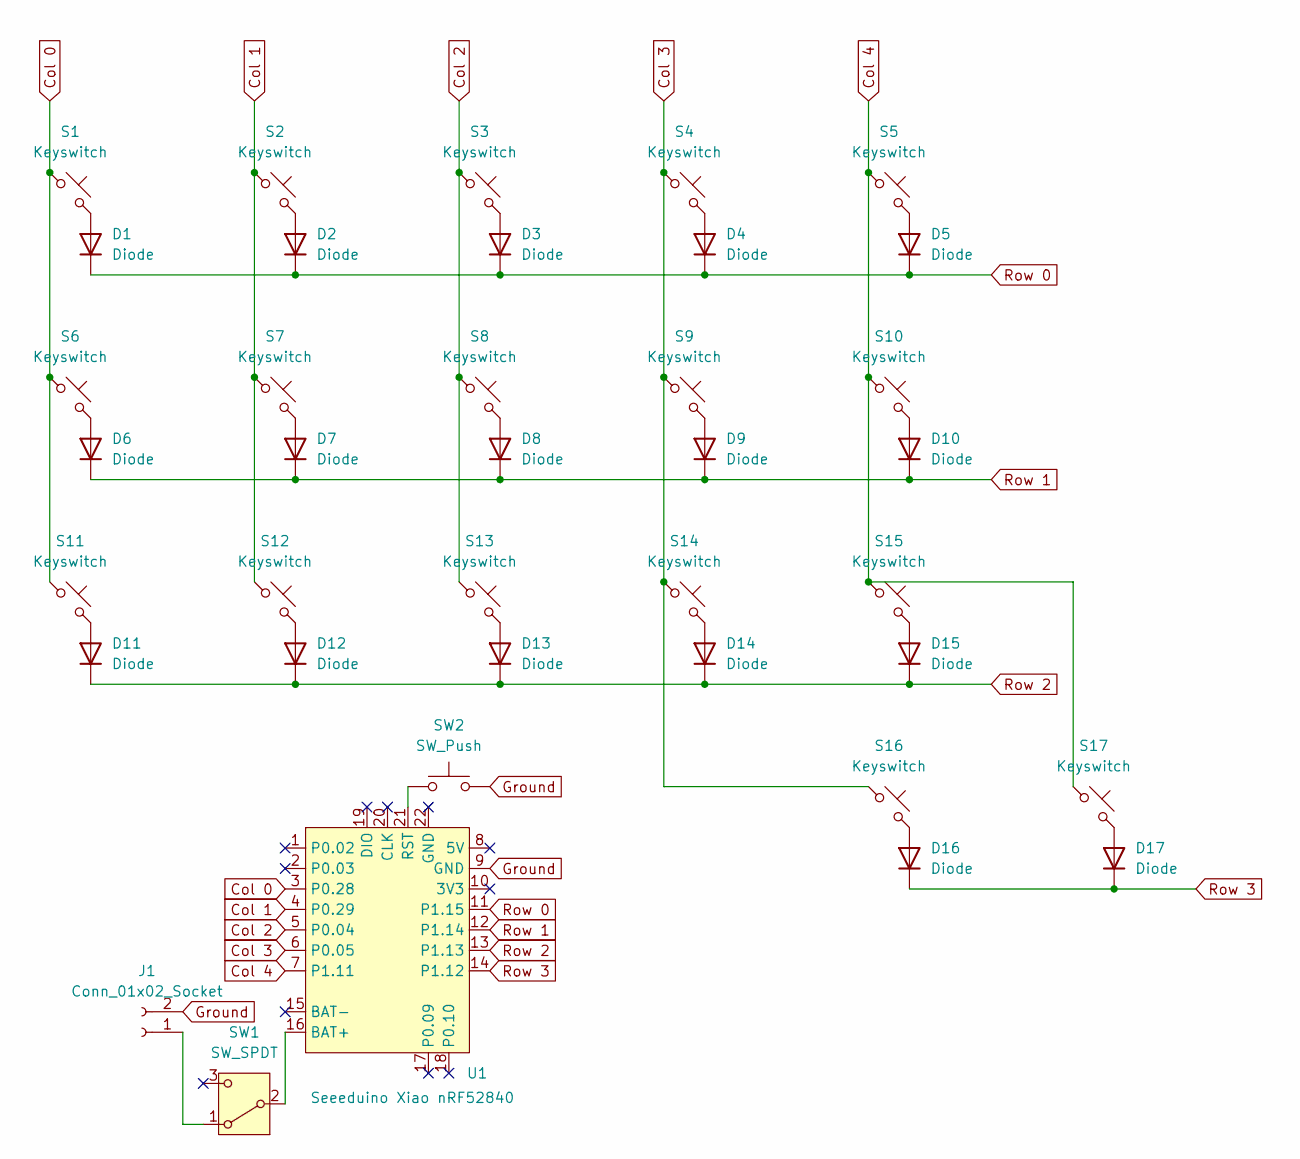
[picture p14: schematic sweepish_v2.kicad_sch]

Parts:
D1, D2, D3, D4, D5, D6, D7, D8, D9, D10, D11, D12, D13, D14, D15, D16, D17: Diode; Diode_SOD-123
J1: Conn_01x02_Socket; JST_PH_S2B-PH-SM4-TB_1x02-1MP_P2.00mm_Horizontal
S1, S2, S3, S4, S5, S6, S7, S8, S9, S10, S11, S12, S13, S14, S15, S16, S17: Keyswitch; Choc_V1_1.00u
SW1: SW_SPDT; SW_MSK12C02-HB
SW2: SW_Push; SW_T1A2QR
U1: Seeeduino Xiao nRF52840; Xiao_nRF52840_AC_Reflow

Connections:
Col 0: S1.1, S6.1, S11.1, U1.3 (P0.28)
Col 1: S2.1, S7.1, S12.1, U1.4 (P0.29)
Col 2: S3.1, S8.1, S13.1, U1.5 (P0.04)
Col 3: S4.1, S9.1, S14.1, S16.1, U1.6 (P0.05)
Col 4: S5.1, S10.1, S15.1, S17.1, U1.7 (P1.11)
Ground: J1.2, SW2.2, U1.9 (GND)
unnamed: D1.2 (A), S1.2
unnamed: D2.2 (A), S2.2
unnamed: D3.2 (A), S3.2
unnamed: D4.2 (A), S4.2
unnamed: D5.2 (A), S5.2
unnamed: D6.2 (A), S6.2
unnamed: D7.2 (A), S7.2
unnamed: D8.2 (A), S8.2
unnamed: D9.2 (A), S9.2
unnamed: D10.2 (A), S10.2
unnamed: D11.2 (A), S11.2
unnamed: D12.2 (A), S12.2
unnamed: D13.2 (A), S13.2
unnamed: D14.2 (A), S14.2
unnamed: D15.2 (A), S15.2
unnamed: D16.2 (A), S16.2
unnamed: D17.2 (A), S17.2
unnamed: J1.1, SW1.1 (A)
unnamed: SW1.2 (B), U1.16 (BAT+)
unnamed: SW2.1, U1.21 (RST)
Row 0: D1.1 (K), D2.1 (K), D3.1 (K), D4.1 (K), D5.1 (K), U1.11 (P1.15)
Row 1: D6.1 (K), D7.1 (K), D8.1 (K), D9.1 (K), D10.1 (K), U1.12 (P1.14)
Row 2: D11.1 (K), D12.1 (K), D13.1 (K), D14.1 (K), D15.1 (K), U1.13 (P1.13)
Row 3: D16.1 (K), D17.1 (K), U1.14 (P1.12)

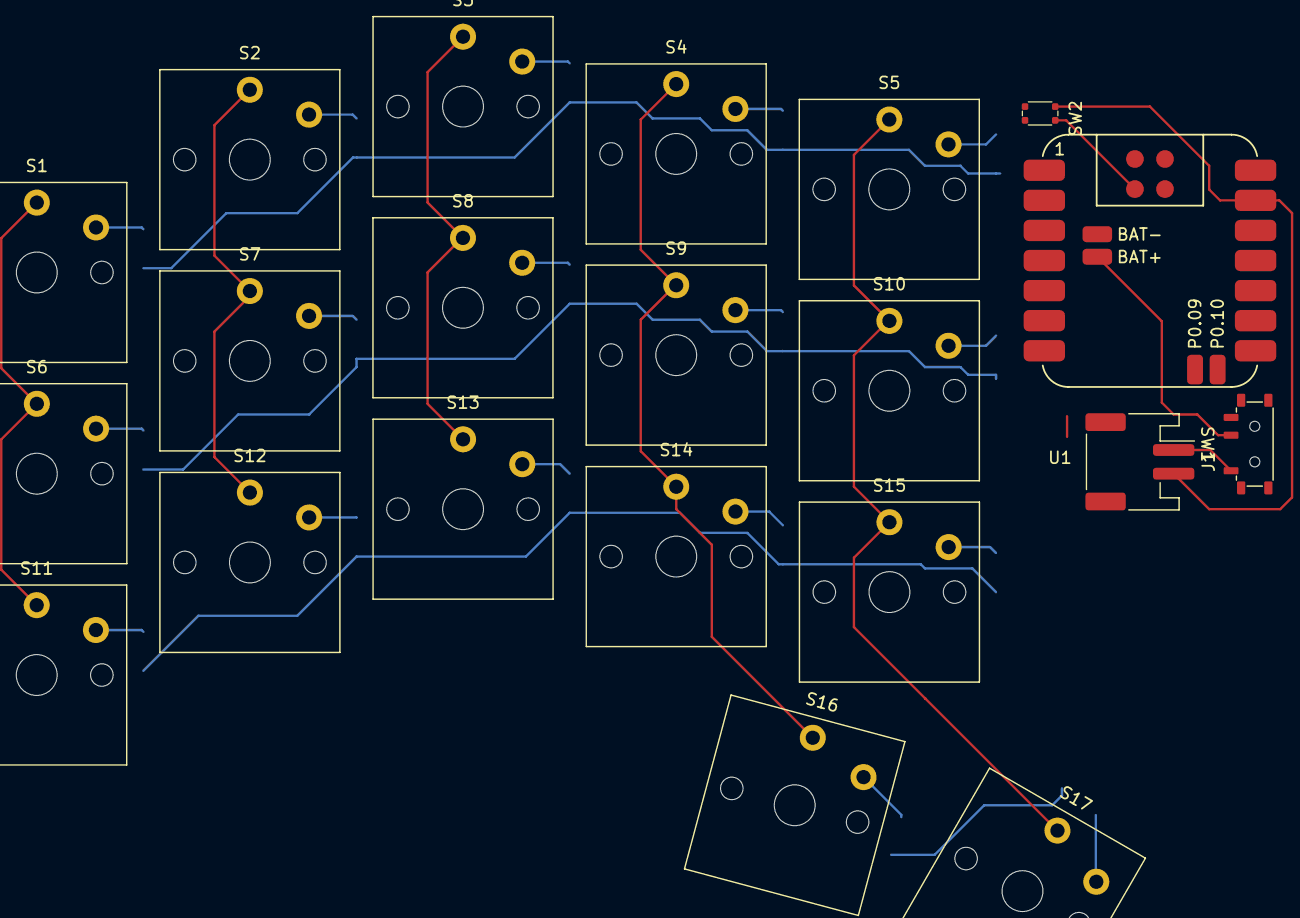
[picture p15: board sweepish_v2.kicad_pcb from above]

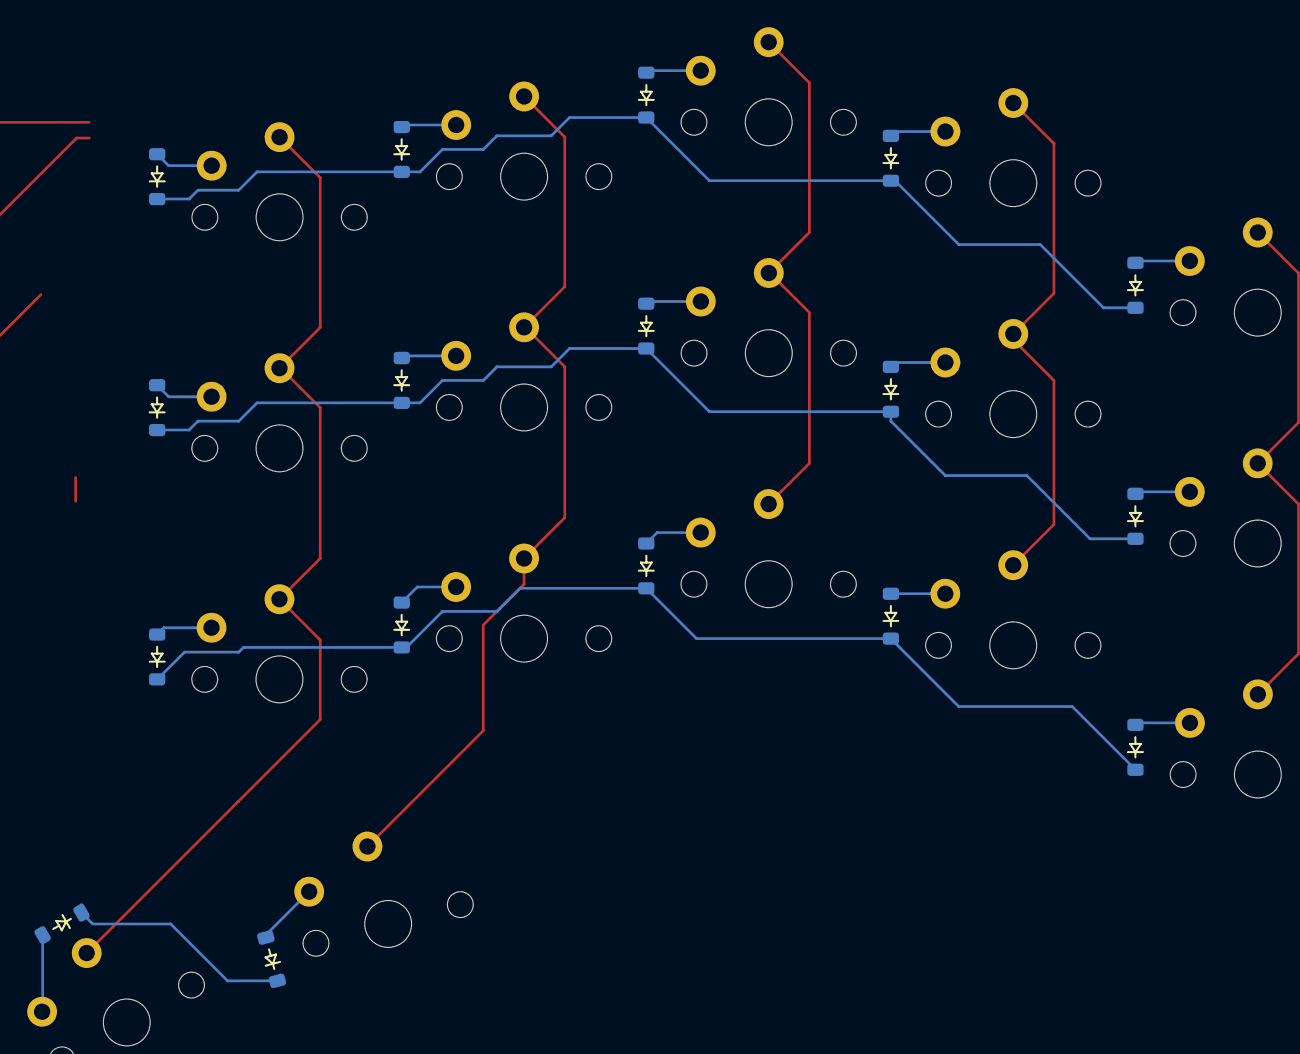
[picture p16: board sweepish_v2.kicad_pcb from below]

Board: 2 copper layers, 38 parts (17 on the bottom side), 30 nets.

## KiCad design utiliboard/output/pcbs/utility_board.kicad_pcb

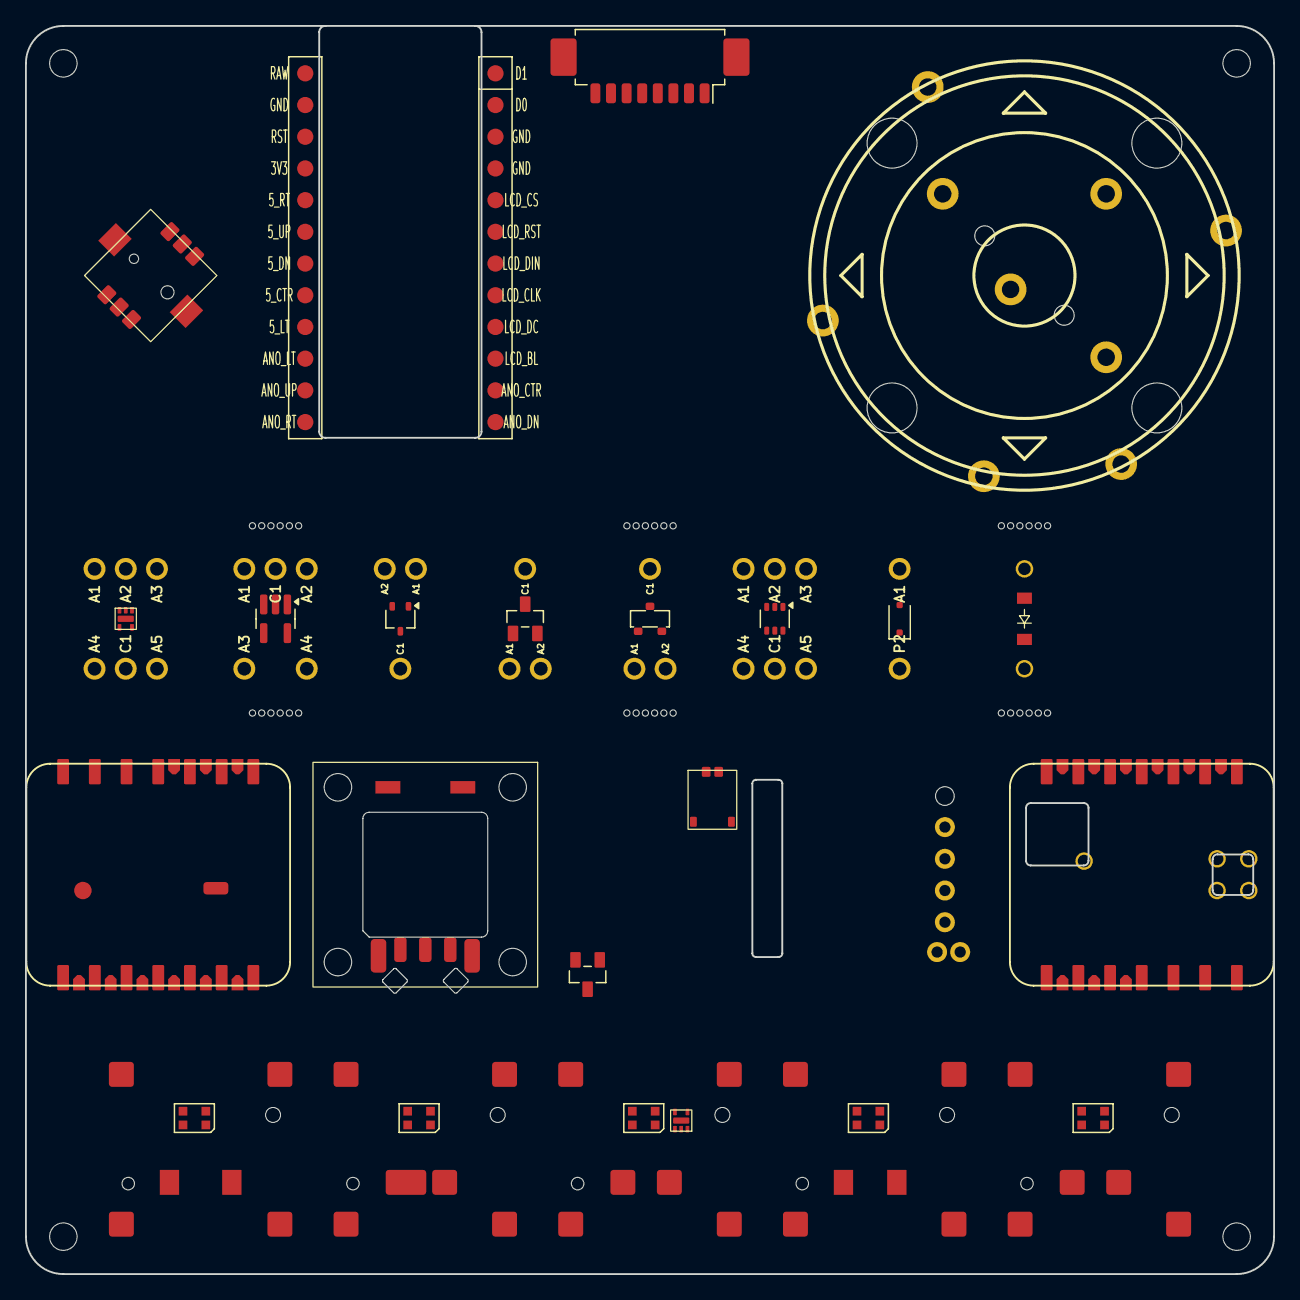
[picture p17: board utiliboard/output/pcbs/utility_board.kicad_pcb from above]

Board: 2 copper layers, 100.0 x 100.0 mm, 47 parts (0 on the bottom side), 76 nets, no tracks yet.

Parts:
CONN1: Molex_PicoBlade_53261-0871_1x08-1MP_P1.25mm_Horizontal
CONN2: Molex_Pico_EZMate_Plus_1x02
D1, D7: D_MMBD4148PLM
D2, D6: BAV70; BAV70 SOT23
D3: SOT-23
D4: D_SOD-323F
D5: diode_tht_sod123
H1, H2: mounting_hole_plated
LED1, LED2, LED3, LED4, LED5: LED_WS2812B-2020_PLCC4_2.0x2.0mm
MCU1: mcu_nice_nano
MDS1: SKRHADE010_naked
MH1, MH2, MH3, MH4: mounting_hole_npth
RE1: ENCODER_ANO
RE2: CKW12
S2, S3, S4, S5, S6: PG1316S
XX1, XX2, XX3, XX4, XX5, XX6: mousebites 2mm; mousebites_25mm
XX7, XX9, XX11, XX12, XX13, XX15, XX16: 5diode_Breakout_Holes
XX8: SC-74A-5_1.55x2.9mm_P0.95mm
XX10: SOT-323_SC-70
XX14: SOT-363_SC-70-6
XX17, XX18: xiao_plus_smd_prod

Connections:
1A1: D1.1, XX7.1
1A2: D1.2, XX7.2
1A3: D1.3, XX7.3
1A4: D1.4, XX7.4
1A5: D1.5, XX7.6
1C1: D1.6, XX7.5
2A1: XX8.1, XX9.3
2A2: XX8.3, XX9.1
2A3: XX8.4, XX9.4
2A4: XX8.5, XX9.5
2C1: XX8.2, XX9.2
3P1: XX10.1, XX11.1
3P2: XX10.2, XX11.2
3P3: XX10.3, XX11.3
3V3: CONN1.1, MCU1.21, XX17.12, XX18.12
4A1: D2.1, XX12.1
4A2: D2.2, XX12.2
4C1: D2.3, XX12.3
5A1: D3.1, XX13.1
5A2: D3.2, XX13.2
5C1: D3.3, XX13.3
5V: LED1.4, LED2.4, LED3.4, LED4.4, LED5.4, XX17.14, XX18.14
5_CTR: MCU1.17, MDS1.2
5_DN: MCU1.18, MDS1.3
5_LT: MCU1.16, MDS1.1
5_RT: MCU1.20, MDS1.6
5_UP: MCU1.19, MDS1.4
6P1: XX14.1, XX15.3
6P2: XX14.2, XX15.2
6P3: XX14.3, XX15.1
6P4: XX14.4, XX15.4
6P5: XX14.5, XX15.5
6P6: XX14.6, XX15.6
7P1: D4.2, XX16.1
7P2: D4.1, XX16.2
ANO_B: RE1.A, RE1.B
ANO_CTR: MCU1.11, RE1.S1
ANO_DN: MCU1.12, RE1.S2
ANO_LT: MCU1.15, RE1.S5
ANO_RT: MCU1.13, RE1.S3
ANO_UP: MCU1.14, RE1.S4
C0: RE2.S1, S2.1, XX17.19, XX18.19
C1: S3.1, XX17.6, XX18.6
C2: S4.1, XX17.21, XX18.21
C3: S5.1, XX17.9, XX18.9
C4: S6.1, XX17.22, XX18.22
GND: CONN1.2, CONN2.1, LED1.2, LED2.2, LED3.2, LED4.2, LED5.2, MCU1.3, MCU1.4, MCU1.23, MDS1.5, RE1.COM_A, RE1.COM_B, RE2.B, S3.3, S4.3, S5.3, S6.3, XX17.13, XX18.13, XX18.27
LCD_BL: CONN1.8, MCU1.10
LCD_CLK: CONN1.4, MCU1.8
LCD_CS: CONN1.5, MCU1.5
LCD_DC: CONN1.6, MCU1.9
LCD_DIN: CONN1.3, MCU1.7
LCD_RST: CONN1.7, MCU1.6
P0.02: XX17.1, XX18.1
P0.03: XX17.2, XX18.2
P0.15: XX17.15, XX18.15
P0.19: XX17.16, XX18.16
P0.28: XX17.3, XX18.3
P0.29: XX17.4, XX18.4
P0.31: XX17.20, XX18.20
P1.01: XX17.17, XX18.17
P1.15: XX17.11, XX18.11
R0: D7.6, XX17.7, XX18.7
R1: D6.3, XX17.8, XX18.8
RAW: CONN2.2, MCU1.24, XX17.28, XX18.28
RST: MCU1.22, XX17.26, XX18.26
ckw12_to: D6.1, RE2.S2
ckw_a: XX17.10, XX18.10
ckw_b: XX17.23, XX18.23
index_home: D7.1, S5.2
inner_home: D7.4, S6.2
middle_home: D7.2, S4.2
pinky_home: D7.5, S2.2
ring_home: D7.3, S3.2
scroll_a: XX17.18, XX18.18
scroll_b: XX17.5, XX18.5

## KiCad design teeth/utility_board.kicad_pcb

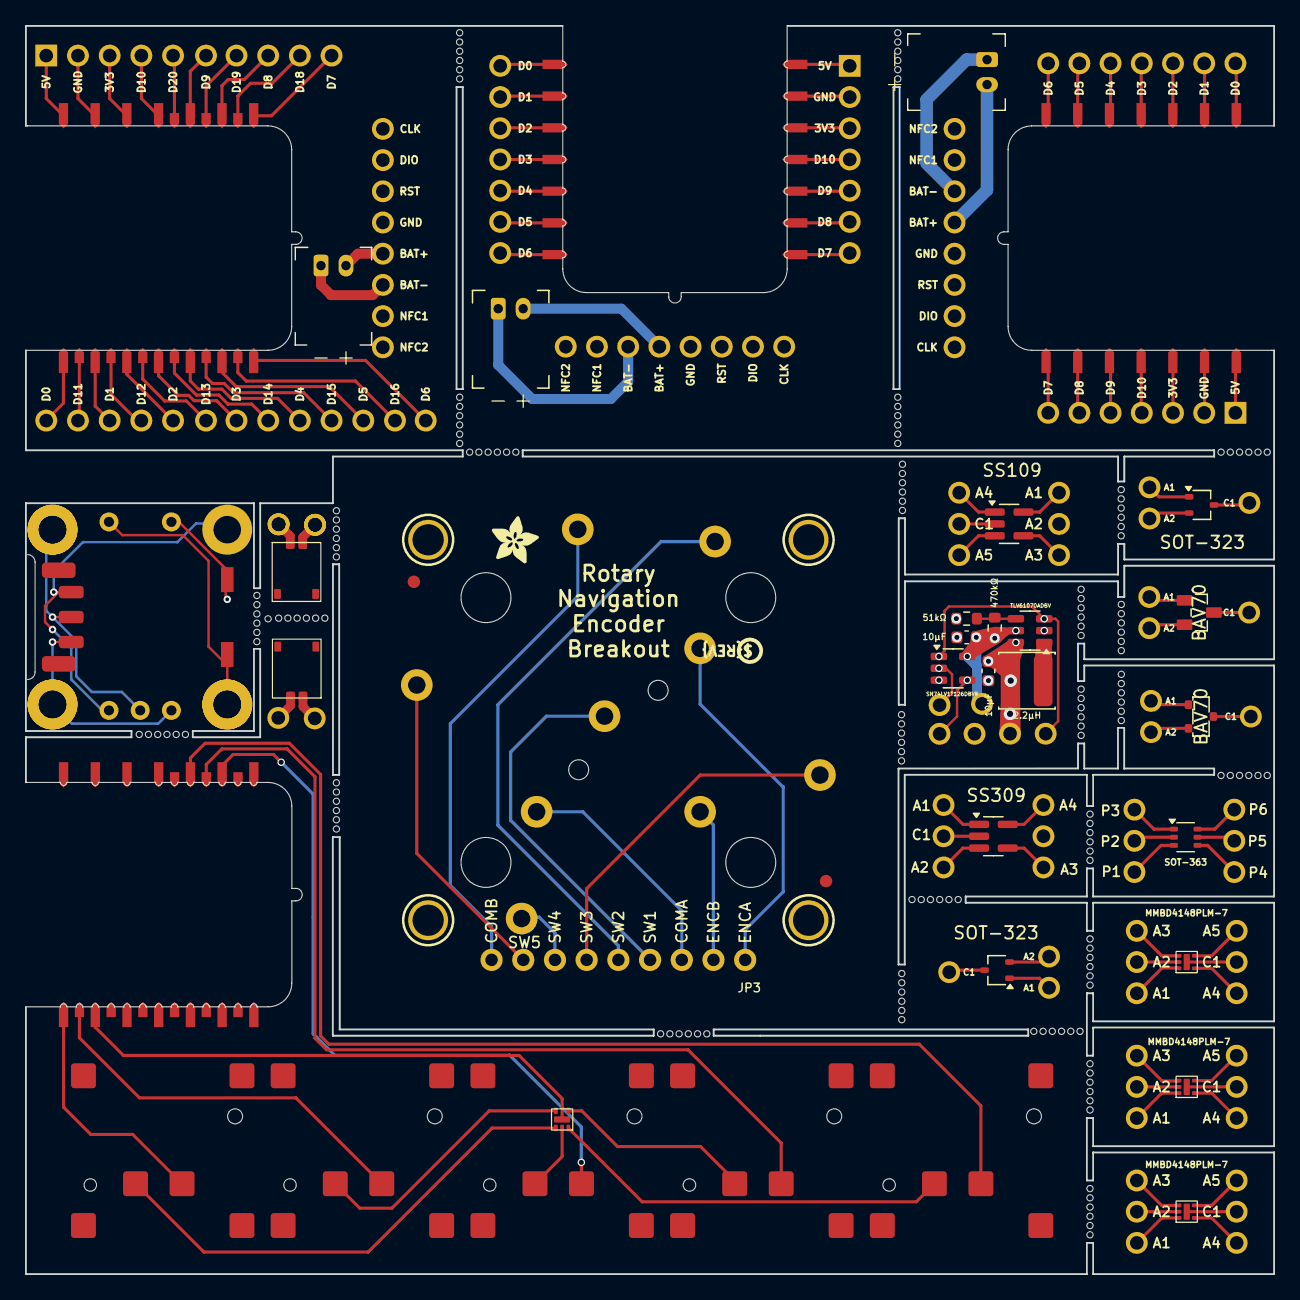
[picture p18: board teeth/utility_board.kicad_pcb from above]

Board: 2 copper layers, 100.1 x 100.0 mm, 54 parts (1 on the bottom side), 107 nets.

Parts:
C1, C2: 10μF; C_0603_1608Metric
CONN1, CONN1#2: Battery Connector; Molex_Pico_EZMate_Plus_1x02
D1, D2, D3, D8: D_MMBD4148PLM
D5: SOT-23
D6: BAV70; BAV70 SOT23
FID3, FID4: FIDUCIAL_1MM
J1, J2#2, J3, J4#2: xiao_plus_cutout
J1#2, J2, J3#2, J4: Conn_01x01_Pin; my_mount_hole_M2_pad
JP3: 1X09_ROUND_70
JST1, JST1#2, JST1#3: battery_connector_jst_ph_2
L1: 2.2μH; L_CJIANG_FTC404030S_4.1x4.1x3.0_SMD
MCU1, MCU2, MCU3: XIAO_Breakout_Holes
R1: 470kΩ; R_0603_1608Metric
R2: 51kΩ; R_0603_1608Metric
S1, S3, S5, S7, S9: PG1316S_Square_Pads
U1: TLV61070ADBV; SOT-23-6
U2: SN74LV1T126DBVR; SOT-23-5
U$25, U$27, U$29, U$30: MOUNTINGHOLE2.5; MOUNTINGHOLE_2.5_PLATED
U$32: ADAFRUIT_3.5MM
U$33: PCBFEAT-REV-040
X1: ENCODER_ANO
XX17, XX18, XX18#2, XX19, XX19#2, XX19#3, XX21, XX21#2, XX21#3, XX22: 5diode_Breakout_Holes

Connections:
1A1: D1.1, XX17.1
1A2: D1.2, XX17.2
1A3: D1.3, XX17.3
1A4: D1.4, XX17.4
1A5: D1.5, XX17.5
1C1: D1.6, XX17.6
2A1: D2.1, XX18.1
2A2: D2.2, XX18.2
2A3: D2.3, XX18.3
2A4: D2.4, XX18.4
2A5: D2.5, XX18.5
2C1: D2.6, XX18.6
3A1: D3.1, XX19.1
3A2: D3.2, XX19.2
3A3: D3.3, XX19.3
3A4: D3.4, XX19.4
3A5: D3.5, XX19.5
3C1: D3.6, XX19.6
3V3_a: J2#2.12, MCU1.12
3V3_b: J3.12, MCU2.12
3V3_c: J4#2.12, MCU3.12
5A1: D5.1, XX21#3.1
5A2: D5.2, XX21#3.2
5C1: D5.3, XX21#3.3
5V: C2.1, J1.14, R1.1, U1.5 (V_{OUT}), U2.5 (VCC)
5V_EN: U1.3 (EN), U2.1
5V_a: J2#2.14, MCU1.14
5V_b: J3.14, MCU2.14
5V_c: J4#2.14, MCU3.14
6A1: D6.1, XX22.1
6A2: D6.2, XX22.2
6C1: D6.3, XX22.3
BAT-: JST1#2.1, MCU1.29
BAT_a: CONN1.2, CONN1#2.2, JST1#2.2, MCU1.28
BOOST_FB: R1.2, R2.1, U1.4 (V_{FB})
BOOST_SW: L1.2, U1.1 (SW)
COMA: JP3.3, X1.COM_A
COMB: JP3.9, X1.COM_B
D0_a: J2#2.1, MCU1.1
D0_b: J3.1, MCU2.1
D0_c: J4#2.1, MCU3.1
D1_a: J2#2.2, MCU1.2
D1_b: J3.2, MCU2.2
D1_c: J4#2.2, MCU3.2
D2_a: J2#2.3, MCU1.3
D2_b: J3.3, MCU2.3
D2_c: J4#2.3, MCU3.3
D3_a: J2#2.4, MCU1.4
D3_b: J3.4, MCU2.4
D3_c: J4#2.4, MCU3.4
D4_a: J2#2.5, MCU1.5
D4_b: J3.5, MCU2.5
D4_c: J4#2.5, MCU3.5
D5_a: J2#2.6, MCU1.6
D5_b: J3.6, MCU2.6
D5_c: J4#2.6, MCU3.6
D6_a: J2#2.7, MCU1.7
D6_b: J3.7, MCU2.7
D6_c: J4#2.7, MCU3.7
D7_a: J2#2.8, MCU1.8
D7_b: J3.8, MCU2.8
D7_c: J4#2.8, MCU3.8
D8_a: J2#2.9, MCU1.9
D8_b: J3.9, MCU2.9
D8_c: J4#2.9, MCU3.9
D9_a: J2#2.10, MCU1.10
D9_b: J3.10, MCU2.10
D9_c: J4#2.10, MCU3.10
D10_a: J2#2.11, MCU1.11
D10_b: J3.11, MCU2.11
D10_c: J4#2.11, MCU3.11
D11_a: J2#2.15, MCU1.15
D12_a: J2#2.16, MCU1.16
D13_a: J2#2.17, MCU1.17
D14_a: J2#2.18, MCU1.18
D15_a: J2#2.19, MCU1.19
D15_b: JST1#3.2, MCU2.19
D15_c: JST1.2, MCU3.19
D16_a: J2#2.20, MCU1.20
D16_b: JST1#3.1, MCU2.20
D16_c: JST1.1, MCU3.20
D17_a: J2#2.21, MCU1.21
D18_a: J2#2.22, MCU1.22
D19_a: J2#2.23, MCU1.23
ENC_A: JP3.1, X1.A
ENC_B: JP3.2, X1.B
GND: C1.2, C2.2, CONN1.1, CONN1#2.1, J1.13, R2.2, U1.2 (GND), U2.3 (GND), XX19#2.6, XX19#3.2
GND_a: J2#2.13, MCU1.13
GND_b: J3.13, MCU2.13
GND_c: J4#2.13, MCU3.13
P0.02: J1.1, S1.2
P0.03: D8.6, J1.2
P0.15: J1.15, S3.2
P1.05: J1.22, S7.2
P1.13: J1.9, S5.2
P1.14: J1.10, S9.2
RAW: C1.1, L1.1, U1.6 (V_{IN})
SW1: JP3.4, X1.S1
SW2: JP3.5, X1.S2
SW3: JP3.6, X1.S3
SW4: JP3.7, X1.S4
SW5: JP3.8, X1.S5
index_home: D8.4, S7.1
inner_home: D8.1, S9.1
middle_home: D8.2, S5.1
pinky_home: D8.3, S1.1
ring_home: D8.5, S3.1

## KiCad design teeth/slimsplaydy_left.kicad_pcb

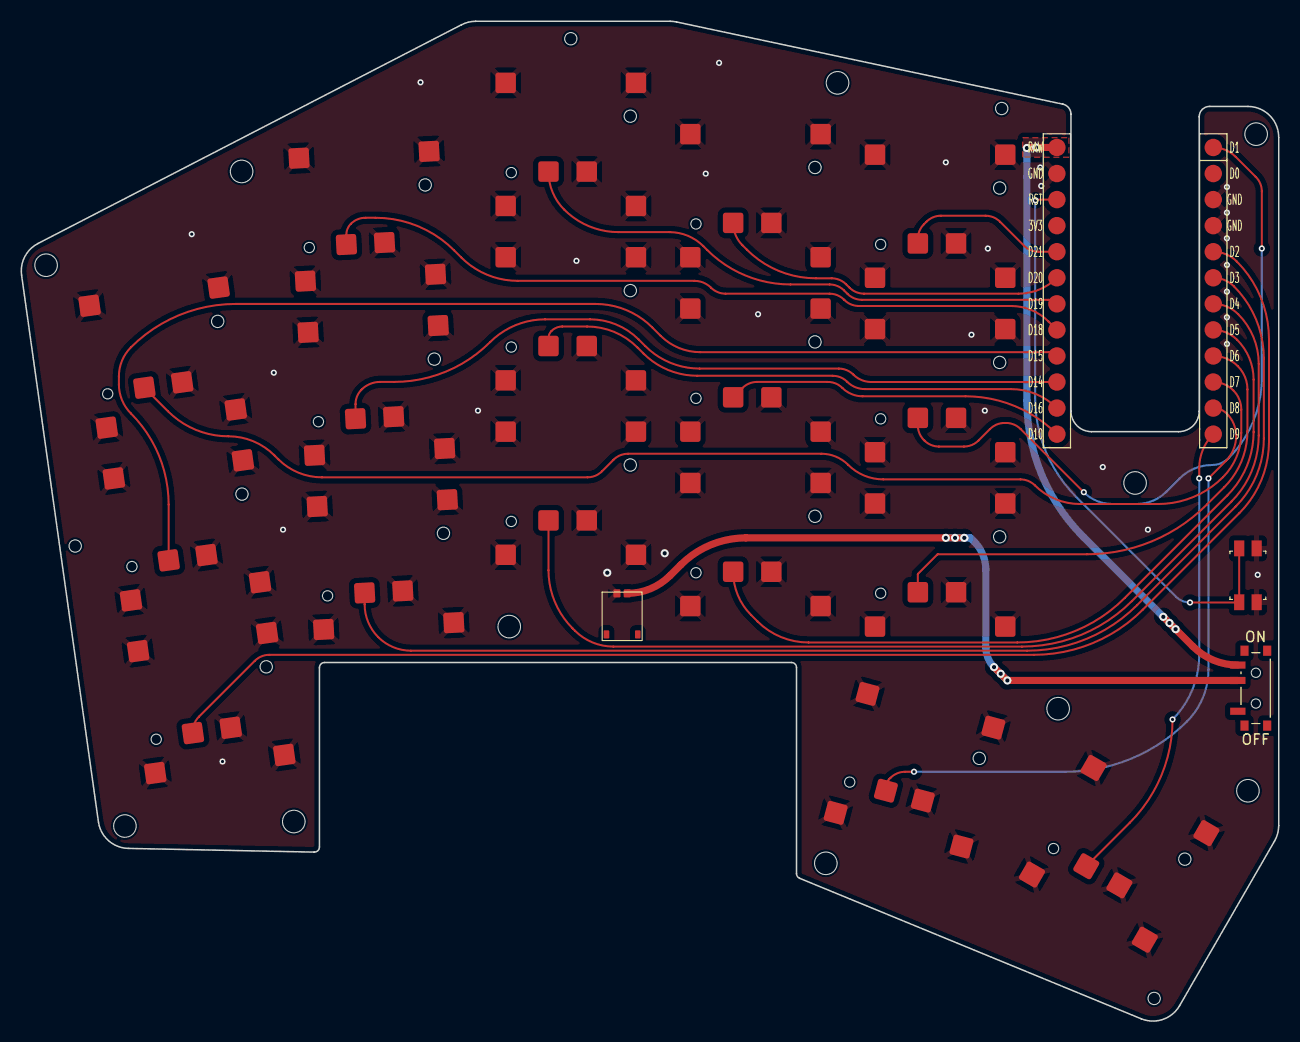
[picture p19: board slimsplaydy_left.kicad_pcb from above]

Board: 2 copper layers, 122.6 x 97.5 mm, 37 parts (1 on the bottom side), 21 nets.

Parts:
CONN1: Battery Connector; Molex_Pico_EZMate_Plus_1x02
MAG1: magsafe
MCU1: nice_nano; mcu_nice_nano
MH1, MH2, MH3, MH4, MH5, MH6, MH7, MH8, MH9, MH10, MH11, MH12, MH13, MH14, MH15: mounting_hole_npth
PWR1: Power SW; power_switch_smd_side
RST1: Reset SW; reset_switch_smd_side
S1, S2, S3, S4, S5, S6, S7, S8, S9, S10, S11, S12, S13, S14, S15, S16, S17: PG1316S

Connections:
BAT_P: CONN1.2, PWR1.2 (B)
GND: CONN1.1, MCU1.3 (GND), MCU1.4 (GND), MCU1.23 (GND), RST1.1, RST1.3, S1.2, S1.3 (B), S2.2, S2.3 (B), S3.2, S3.3 (B), S4.2, S4.3 (B), S5.2, S5.3 (B), S6.2, S6.3 (B), S7.2, S7.3 (B), S8.2, S8.3 (B), S9.2, S9.3 (B), S10.2, S10.3 (B), S11.2, S11.3 (B), S12.2, S12.3 (B), S13.2, S13.3 (B), S14.2, S14.3 (B), S15.2, S15.3 (B), S16.2, S16.3 (B), S17.2, S17.3 (B)
RAW: MCU1.24 (BAT+), PWR1.3 (C)
RST: MCU1.22 (RST), RST1.2, RST1.4
finger_index_bottom: MCU1.8 (P0.24), S10.1
finger_index_home: MCU1.13 (P0.09-LF), S11.1
finger_index_top: MCU1.19 (P0.29-LF), S12.1
finger_inner_bottom: MCU1.9 (P1.00), S13.1
finger_inner_home: MCU1.1 (P0.06), S14.1
finger_inner_top: MCU1.20 (P0.31-LF), S15.1
finger_middle_bottom: MCU1.7 (P0.22), S7.1
finger_middle_home: MCU1.14 (P0.10-LF), S8.1
finger_middle_top: MCU1.18 (P0.02-LF), S9.1
finger_pinky_bottom: MCU1.5 (P0.17), S1.1
finger_pinky_home: MCU1.16 (P1.13-LF), S2.1
finger_pinky_top: MCU1.10 (P0.11), S3.1
finger_ring_bottom: MCU1.6 (P0.20), S4.1
finger_ring_home: MCU1.15 (P1.11-LF), S5.1
finger_ring_top: MCU1.17 (P1.15-LF), S6.1
thumb_reachy_fan: MCU1.12 (P1.06-LF), S17.1
thumb_tucky_fan: MCU1.11 (P1.04-LF), S16.1

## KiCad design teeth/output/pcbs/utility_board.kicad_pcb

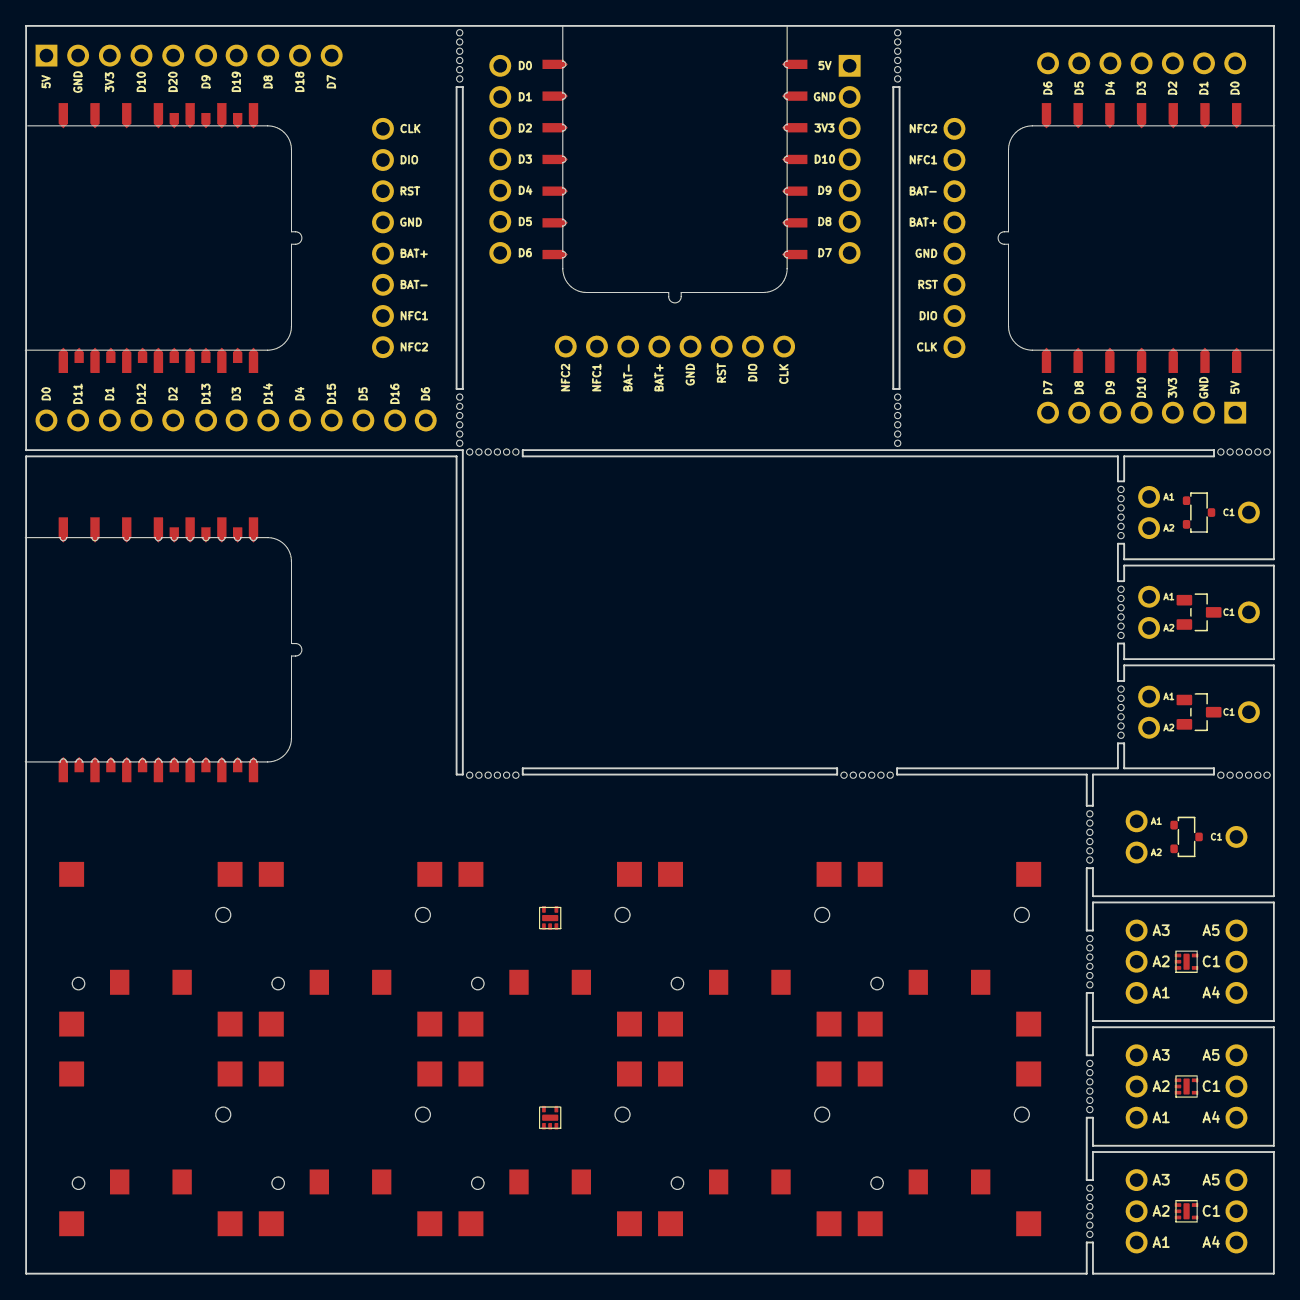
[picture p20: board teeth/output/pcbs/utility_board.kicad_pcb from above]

Board: 2 copper layers, 100.0 x 100.0 mm, 49 parts (0 on the bottom side), 98 nets, no tracks yet.

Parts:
D1, D2, D3, D8, D9: D_MMBD4148PLM
D4, D6: BAV70; BAV70 SOT23
D5, D7: SOT-23
J1, J2, J3, J4: xiao_plus_cutout
MCU1, MCU2, MCU3: XIAO_Breakout_Holes
S1, S2, S3, S4, S5, S6, S7, S8, S9, S10: CPG1316S01D02_mikeholscher
XX1, XX2, XX3, XX4, XX5, XX6, XX7, XX8, XX9, XX10, XX11, XX12, XX13, XX14, XX15, XX16: mousebites 2mm; mousebites_25mm
XX17, XX18, XX19, XX20, XX21, XX22, XX23: 5diode_Breakout_Holes

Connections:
1A1: D1.1, XX17.1
1A2: D1.2, XX17.2
1A3: D1.3, XX17.3
1A4: D1.4, XX17.4
1A5: D1.5, XX17.5
1C1: D1.6, XX17.6
2A1: D2.1, XX18.1
2A2: D2.2, XX18.2
2A3: D2.3, XX18.3
2A4: D2.4, XX18.4
2A5: D2.5, XX18.5
2C1: D2.6, XX18.6
3A1: D3.1, XX19.1
3A2: D3.2, XX19.2
3A3: D3.3, XX19.3
3A4: D3.4, XX19.4
3A5: D3.5, XX19.5
3C1: D3.6, XX19.6
3V3_a: J2.12, MCU1.12
3V3_b: J3.12, MCU2.12
3V3_c: J4.12, MCU3.12
4A1: D4.1, XX20.1
4A2: D4.2, XX20.2
4C1: D4.3, XX20.3
5A1: D5.1, XX21.1
5A2: D5.2, XX21.2
5C1: D5.3, XX21.3
5V_a: J2.14, MCU1.14
5V_b: J3.14, MCU2.14
5V_c: J4.14, MCU3.14
6A1: D6.1, XX22.1
6A2: D6.2, XX22.2
6C1: D6.3, XX22.3
7A1: D7.1, XX23.1
7A2: D7.2, XX23.2
7C1: D7.3, XX23.3
D0_a: J2.1, MCU1.1
D0_b: J3.1, MCU2.1
D0_c: J4.1, MCU3.1
D1_a: J2.2, MCU1.2
D1_b: J3.2, MCU2.2
D1_c: J4.2, MCU3.2
D2_a: J2.3, MCU1.3
D2_b: J3.3, MCU2.3
D2_c: J4.3, MCU3.3
D3_a: J2.4, MCU1.4
D3_b: J3.4, MCU2.4
D3_c: J4.4, MCU3.4
D4_a: J2.5, MCU1.5
D4_b: J3.5, MCU2.5
D4_c: J4.5, MCU3.5
D5_a: J2.6, MCU1.6
D5_b: J3.6, MCU2.6
D5_c: J4.6, MCU3.6
D6_a: J2.7, MCU1.7
D6_b: J3.7, MCU2.7
D6_c: J4.7, MCU3.7
D7_a: J2.8, MCU1.8
D7_b: J3.8, MCU2.8
D7_c: J4.8, MCU3.8
D8_a: J2.9, MCU1.9
D8_b: J3.9, MCU2.9
D8_c: J4.9, MCU3.9
D9_a: J2.10, MCU1.10
D9_b: J3.10, MCU2.10
D9_c: J4.10, MCU3.10
D10_a: J2.11, MCU1.11
D10_b: J3.11, MCU2.11
D10_c: J4.11, MCU3.11
D11_a: J2.15, MCU1.15
D12_a: J2.16, MCU1.16
D13_a: J2.17, MCU1.17
D14_a: J2.18, MCU1.18
D15_a: J2.19, MCU1.19
D16_a: J2.20, MCU1.20
D17_a: J2.21, MCU1.21
D18_a: J2.22, MCU1.22
D19_a: J2.23, MCU1.23
GND_a: J2.13, MCU1.13
GND_b: J3.13, MCU2.13
GND_c: J4.13, MCU3.13
P0.02: J1.1, S1.2, S2.2
P0.03: D8.6, J1.2
P0.15: J1.15, S3.2, S4.2
P1.03: D9.6, J1.21
P1.05: J1.22, S7.2, S8.2
P1.13: J1.9, S5.2, S6.2
P1.14: J1.10, S9.2, S10.2
index_home: D8.1, S7.1
index_top: D9.1, S8.1
inner_home: D8.4, S9.1
inner_top: D9.4, S10.1
middle_home: D8.2, S5.1
middle_top: D9.2, S6.1
pinky_home: D8.5, S1.1
pinky_top: D9.5, S2.1
ring_home: D8.3, S3.1
ring_top: D9.3, S4.1

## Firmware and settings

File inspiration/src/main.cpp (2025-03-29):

//***************************************************************************************************
//*  Main code                                                                                      *
//*  By Ed Smallenburg <https://github.com/Edzelf/>                                                 *
//***************************************************************************************************
//***************************************************************************************************
// Board:            ESP32 Development board.                                                       *
// Partition scheme: Default 4MB with spiffs (1.2MB APP/1.5MB SPIFFS)                               *
//***************************************************************************************************
// This sketch uses SPIFFS for the web interface files.  For installation of FS tools see:          *
// https://randomnerdtutorials.com/install-esp32-filesystem-uploader-arduino-ide/                   *
//***************************************************************************************************
//***************************************************************************************************
// Wiring.                                                                                          *
// ------------------------------------------------------------------------------------------------ *
// ESP32dev Signal  Connected to                Remarks                                             *
// -------- ------  --------------              ----------------------------------------------      *
// GPIO0    BOOT    Reserved bootloader         Also 2nd start button for test                      *
// GPIO1    TXD0    Reserved serial output                                                          *
// GPIO2            Built-in LED                                                                    *
// GPIO3    RXD0    Reserved serial input                                                           *
// GPIO4            -                                                                               *
// GPIO5            Big button                  (active low)                                        *
// GPIO12           Neopixel panel DIN                                                              *
// GPIO14           I2S BCLK naar bijv. MAX98357A / PCM5102                                         *
// GPIO15           -                                                                               *
// GPIO16   RXD2    -                                                                               *
// GPIO17   TXD2    -                                                                               *
// GPIO18   SCK     -                                                                               *
// GPIO19   MISO    -                                                                               *
// GPIO21           SDA for I2C (DS3132)                                                            *
// GPIO22           SCK for I2C (DS3132)                                                            *
// GPIO23   MOSI    -                                                                               *
// GPIO25   -       audio output van interne DAC.                                                   *
// GPIO26   -       audio output van interne DAC.                                                   *
// GPIO27   -       I2S DIN  naar bijv. MAX98357A / PCM5102                                         *
// GPIO32   -       Enable VIN of PCM5102                                                           *
// GPIO33   -       I2S LRC  naar bijv. MAX98357A / PCM5102                                         *
// GPIO34   -       GPS TX                      (input only pin)                                    *
// GPIO35   -       -                           (input only pin)                                    *
// -------  ------  ----------------                                                                *
// GND      -       Power supply GND                                                                *
// VCC 5 V  -       Power supply                                                                    *
// VCC 5 V  -       Power supply                                                                    *
// 3.3 V    -       GPS Vcc                                                                         *
// EN       -       -                                                                               *
//***************************************************************************************************
// 11-10-2021, ES: First set-up.                                                                    *
// 01-11-2021, ES: Add registratie logging.                                                         *
// 22-11-2021, ES: Output to MAX98357A.                                                             *
// 23-11-2021, ES: Log in required.                                                                 *
// 26-11-2021, ES: Replaced display with Neopixel panels.                                           *
// 03-12-2021, ES: Show IP-address.                                                                 *
// 08-12-2021, ES: Grant access using client IP address.                                            *
// 09-12-2021, ES: Rotate display 90 degrees left.                                                  *
// 16-12-2021, ES: left and rigth arrows to display character set.                                  *
// 09-03-2022, ES: Front and back Neopixel panels.                                                  *
// 10-03-2022, ES: Stoplicht/pijl model voor signalering op neopixel front panel.                   *
// 14-03-2022, ES: Pijlen links/rechts omwisselbaar.                                                *
// 01-04-2022, ES: Audio via PCM5102.                                                               *
// 01-04-2022, ES: Pijlen links/rechts/stop/go altijd rood of groen.                                *
// 05-04-2022, ES: Toon drukknop en geanimeerde pijl op front panel in rust.                        *
// 12-05-2022, ES: Replaced I2C driver with Arduino "Wire".                                         *
// 20-08-2022, ES: Correctie i.v.m. veranderde SPIFF functie.                                       *
// 30-09-2022, ES: Correctie WiFi event logging.                                                    *
//***************************************************************************************************
#define OTA                                                 // OTA should be enabled (or not)
#
#include <Arduino.h>
#include <WiFi.h>
#include <soc/soc.h>                                        // For brown-out detector setting
#include <soc/rtc_cntl_reg.h>                               // For brown-out detector setting
#ifdef OTA
  #include <ArduinoOTA.h>
#endif
#include <AsyncTCP.h>
#include <ESPAsyncWebServer.h>
#include <SPIFFS.h>
#include <freertos/task.h>
#include <freertos/queue.h>
#include <nvs_flash.h>
#include <nvs.h>
#include <esp_partition.h>
#include <WiFiMulti.h>
#include <lwip/dns.h>
#include <ESPmDNS.h>
#include <TinyGPS++.h>                                      // For GPS
#include <time.h>
#include <stdio.h>
#include <string.h>
#include <vector>
#include <Wire.h>
#include <driver/i2s.h>                                     // Driver for I2S output
#include "mp3_decoder.h"                                    // include libhelix_HMP3DECODER
#include <NeoPixelBus.h>                                    // For NeoPixel output
#include "charset.hpp"                                      // Neopixel partial charset
#define DEBUG_BUFFER_SIZE 150
#define NVSBUFSIZE        150                               // Longest expected string for nvsgetstr
#define MAXKEYS           40                                // Max. number of NVS keys in table
#define BUTTON0           5                                 // Start button, LOW is active
#define BUTTON1           0                                 // Start button 2, LOW is active

//#define INTERNALDAC                                       // Define for internal DAC usage for I2S
                                                            // Needs platform = espressif32@3.1.0 !!!!
// INTERNALDAC does not seem to work with higher versions of framework.  Do a test.
#ifdef INTERNALDAC
  #if ESP_ARDUINO_VERSION_MAJOR >= 2
    #error Internal DAC will not work in this version of the platform.  Use espressif32@3.1.0.
  #endif
#endif


#define NAME        "HIP"                                   // Ident, also used for AP network.
#define VERSION     "Sat, 20 Aug 2022 10:30:00 GMT"

#define FSIF              true                              // Format SPIFFS if not existing
#define QSIZ              10                                // Number of entries in play queue
#define DS3231_ADDRESS    0x68                              // I2C address of RTC
#define DS3231_TIME       0x00                              // Time register
#define DS3231_STATUSREG  0x0F                              // Status register
#define DS3231_TEMPREG    0x11                              // Temperature register 10-bit

// MP3
#define I2S_ENABLE        32                                // Enable I2S/Amp if used
#define I2S_BCK_PIN       14                                // I2S BCLK naar MAX98357A / PCM5102
#define I2S_LCK_PIN       33                                // I2S LRC naar MAX98357A / PCM5102
#define I2S_DIN_PIN       27                                // I2S DIN naar MAX98357A / PCM5102
#define FRAMESIZE         1152                              // Max. frame size in bytes (mp3)
#define OUTSIZE           2048                              // Max number of samples per channel (mp3)

// GPS
#define GPSSERIAL         Serial2                           // Second serial used for GPS

// Neopixel displays (2x3 modules 8x8)
#define NEO_PANELS        8                                 // Number of panels
#define NEOPIX_PIN        12                                // GPIO for Neopixel displays
#define NEOPIX_COUNT      512                               // Total number of pixels

//***************************************************************************************************
// Forward declarations.                                                                            *
//***************************************************************************************************
esp_err_t   nvsclear() ;
bool        nvssearch ( const char* key ) ;
String      nvsgetstr ( const char* key ) ;
esp_err_t   nvssetstr ( const char* key, String val ) ;
uint32_t    a2tohex ( const char* hstr ) ;
uint32_t    a8tohex ( const char* hstr ) ;
String      getContentType ( String filename ) ;
String      httpheader ( String contentstype ) ;
String      readprefs ( bool output ) ;
void        readprefs ( AsyncWebServerRequest *request ) ;
void        writeprefs ( AsyncWebServerRequest *request ) ;
const char* analyzeCmd ( const char* str ) ;
const char* analyzeCmd ( const char* par, const char* val ) ;
void        getTimeTxt() ;
void        setRtcTime ( const long int t ) ;
bool        openRegfile() ;


//***************************************************************************************************
// Various structs and enums.                                                                       *
//***************************************************************************************************
struct WifiInfo_t                                // For list with WiFi info
{
  uint8_t inx ;                                  // Index as in "wifi_00"
  char*   ssid ;                                 // SSID for an entry
  char*   passphrase ;                           // Passphrase for an entry
} ;


struct nvs_entry
{
  uint8_t  Ns ;                                  // Namespace ID
  uint8_t  Type ;                                // Type of value
  uint8_t  Span ;                                // Number of entries used for this item
  uint8_t  Chunkindex ;                          // Reserved, Should be 0xFF for non-blob types
  uint32_t CRC ;                                 // CRC
  char     Key[16] ;                             // Key in Ascii
  uint64_t Data ;                                // Data in entry
} ;

struct nvs_page                                  // For nvs entries
{ // 1 page is 4096 bytes
  uint32_t  State ;
  uint32_t  Seqnr ;
  uint8_t   version ;
  uint8_t   Unused[19] ;
  uint32_t  CRC ;
  uint8_t   Bitmap[32] ;
  nvs_entry Entry[126] ;
} ;

struct keyname_t                                  // For keys in NVS
{
  char      Key[16] ;                             // Mac length is 15 plus delimeter
} ;

struct qdata_struct                               // Structure of date in playqueue
{
  __attribute__((aligned(4))) char filename[64] ; // File to play
  int pause ;                                     // Pause, silence period in msec
} ;

struct qdisp_struct                               // Structure of date in dispqueue
{
  bool hit ;                                      // Hit or not
  int  volgnummer ;
} ;

enum model_t  { STOPLICHT, PIJL } ;               // Mogelijke keuzes hit/nohit signalering
enum lr_t     { RECHTS, LINKS } ;                 // Keuzes rechtsuit / links uit
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
void loop()
{
  delay ( 100 ) ;
  if ( buttonreq )                                        // Button pushed?
  {
    handle_button() ;                                     // Yes, handle the button
    vTaskDelay ( 5000 / portTICK_PERIOD_MS ) ;            // 5 seconds dead period
    buttonreq = false ;
  }
  if ( resetreq )                                         // Reset requested?
  {
    delay ( 1000 ) ;                                      // Yes, wait some time
    ESP.restart() ;                                       // Reboot
  }
  if ( pwresetreq )                                       // Reset all passwords?
  {
    pwresetreq = false ;                                  // Yes, clear request
    dbgprint ( "Password reset requested" ) ;             // Show it
    nvs_erase_key ( nvshandle, "userpw" ) ;               // Yes, reset user password
    nvs_erase_key ( nvshandle, "adminpw" ) ;              // and admin password
    nvs_erase_key ( nvshandle, "wifipw" ) ;               // and WiFi password
  }
  scanserial() ;                                          // Handle serial input
  scanGPSserial() ;                                       // Listen for GPS info
  if ( errorcount >= 1000 )                               // Too much errors?
  {
    dbgprint ( "Errorcount too high!  Reset.." ) ;
    resetreq = true ;                                     // Yes, force reset
  }
  #ifdef OTA
    ArduinoOTA.handle() ;                                 // Check for OTA
  #endif
  xmaincount++ ;                                          // Count number of loops
}

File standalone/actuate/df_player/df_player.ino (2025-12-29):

/***************************************************
 DFPlayer - A Mini MP3 Player For Arduino
 <https://www.dfrobot.com/product-1121.html>
 
 ***************************************************
 This example shows the all the function of library for DFPlayer.
 
 Created 2016-12-07
 By [Angelo qiao](Angelo.qiao@dfrobot.com)
 
 GNU Lesser General Public License.
 See <http://www.gnu.org/licenses/> for details.
 All above must be included in any redistribution
 ****************************************************/

/***********Notice and Trouble shooting***************
 1.Connection and Diagram can be found here
<https://www.dfrobot.com/wiki/index.php/DFPlayer_Mini_SKU:DFR0299#Connection_Diagram>
 2.This code is tested on Arduino Uno, Leonardo, Mega boards.
 ****************************************************/

 /* Notes from hadoopmarc
   - edited for ESP32 use only
   - needs external 5V
   - the read commands do not seem to work on this mp3 player
   - output sound was OK on SPK_1/SPK_2, DAC_L and DAC_R pins
   - only tried the suggested naming in /01/001.mp3, etc.
 */

#include <Arduino.h>
#include <DFRobotDFPlayerMini.h>
#include <esp32_wiring.h>  // Implies setting serial2RX and serial2TX GPIO ports

DFRobotDFPlayerMini myDFPlayer;
void printDetail(uint8_t type, int value);

void setup()
{
  esp32_wiring_setup();
  Serial.begin(115200);
  Serial2.begin(9600, SERIAL_8N1, serial2RX, serial2TX);
  Serial.println();
  Serial.println(F("DFRobot DFPlayer Mini Demo"));
  Serial.println(F("Initializing DFPlayer ... (May take 3~5 seconds)"));
  
  // Use Serial2 to communicate with mp3 DFPlayer
  if (!myDFPlayer.begin(Serial2, /*isACK = */true, /*doReset = */true)) {
    Serial.println(F("Unable to begin:"));
    Serial.println(F("1.Please recheck the connection!"));
    Serial.println(F("2.Please insert the SD card!"));
    while(true);
  }
  delay(5000);
  Serial.println(F("DFPlayer Mini online."));
  
  myDFPlayer.setTimeOut(2000); //Set serial communictaion time out 500ms
  Serial.println(F("Timeout set"));
  //----Set volume----
  myDFPlayer.volume(20);  //Set volume value (0~30).
  Serial.println(F("Volume set"));
  myDFPlayer.volumeUp(); //Volume Up
  myDFPlayer.volumeDown(); //Volume Down
  
  //----Set different EQ----
  myDFPlayer.EQ(DFPLAYER_EQ_NORMAL);
  Serial.println(F("Equalization set"));
//  myDFPlayer.EQ(DFPLAYER_EQ_POP);
//  myDFPlayer.EQ(DFPLAYER_EQ_ROCK);
//  myDFPlayer.EQ(DFPLAYER_EQ_JAZZ);
//  myDFPlayer.EQ(DFPLAYER_EQ_CLASSIC);
//  myDFPlayer.EQ(DFPLAYER_EQ_BASS);
  
  //----Set device we use SD as default----
//  myDFPlayer.outputDevice(DFPLAYER_DEVICE_U_DISK);
  myDFPlayer.outputDevice(DFPLAYER_DEVICE_SD);
  Serial.println(F("Output device set"));
//  myDFPlayer.outputDevice(DFPLAYER_DEVICE_AUX);
//  myDFPlayer.outputDevice(DFPLAYER_DEVICE_SLEEP);
//  myDFPlayer.outputDevice(DFPLAYER_DEVICE_FLASH);
  
//   //----Mp3 control----
// //  myDFPlayer.sleep();     //sleep
// //  myDFPlayer.reset();     //Reset the module
// //  myDFPlayer.enableDAC();  //Enable On-chip DAC
// //  myDFPlayer.disableDAC();  //Disable On-chip DAC
// //  myDFPlayer.outputSetting(true, 15); //output setting, enable the output and set the gain to 15
  
//   //----Mp3 play----
//   myDFPlayer.next();  //Play next mp3
//   delay(1000);
//   myDFPlayer.previous();  //Play previous mp3
//   delay(1000);
//   myDFPlayer.play(1);  //Play the first mp3
//   delay(1000);
//   myDFPlayer.loop(1);  //Loop the first mp3
//   delay(1000);
//   myDFPlayer.pause();  //pause the mp3
//   delay(1000);
//   myDFPlayer.start();  //start the mp3 from the pause
//   delay(1000);
//   myDFPlayer.playFolder(15, 4);  //play specific mp3 in SD:/15/004.mp3; Folder Name(1~99); File Name(1~255)
//   delay(1000);
//   myDFPlayer.enableLoopAll(); //loop all mp3 files.
//   delay(1000);
//   myDFPlayer.disableLoopAll(); //stop loop all mp3 files.
//   delay(1000);
//   myDFPlayer.playMp3Folder(4); //play specific mp3 in SD:/MP3/0004.mp3; File Name(0~65535)
//   delay(1000);
//   myDFPlayer.advertise(3); //advertise specific mp3 in SD:/ADVERT/0003.mp3; File Name(0~65535)
//   delay(1000);
//   myDFPlayer.stopAdvertise(); //stop advertise
//   delay(1000);
//   myDFPlayer.playLargeFolder(2, 999); //play specific mp3 in SD:/02/004.mp3; Folder Name(1~10); File Name(1~1000)
//   delay(1000);
//   myDFPlayer.loopFolder(5); //loop all mp3 files in folder SD:/05.
//   delay(1000);
//   myDFPlayer.randomAll(); //Random play all the mp3.
//   delay(1000);
//   myDFPlayer.enableLoop(); //enable loop.
//   delay(1000);
//   myDFPlayer.disableLoop(); //disable loop.
//   delay(1000);

  //----Read imformation----
  Serial.println(myDFPlayer.readState()); //read mp3 state
  Serial.println(myDFPlayer.readVolume()); //read current volume
  Serial.println(myDFPlayer.readEQ()); //read EQ setting
  Serial.println(myDFPlayer.readFileCounts()); //read all file counts in SD card
  Serial.println(myDFPlayer.readCurrentFileNumber()); //read current play file number
  Serial.println(myDFPlayer.readFileCountsInFolder(1)); //read file counts in folder SD:/01}
}

void loop()
{
  static unsigned long timer = millis();
  
  if (millis() - timer > 10000) {
    timer = millis();
    myDFPlayer.next();  //Play next mp3 every 3 second.
    Serial.println(F("Play next started"));
  }
  // delay(1000);
  // myDFPlayer.pause();
  // delay(1000);
  // myDFPlayer.start();

  if (myDFPlayer.available()) {
    printDetail(myDFPlayer.readType(), myDFPlayer.read()); //Print the detail message from DFPlayer to handle different errors and states.
    Serial.println(F("Details printed"));
  }
}
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

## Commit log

2025-03-29 Adds the documentation of the inspiration project
    [2023-01-01_001.csv]
2025-04-07 Update red_button.ino
    een regel //test toegevoegd om even wat uit te proberen
2025-06-08 Adds electronic circuit for 12V 1A load driven my MCU
    [driver-12V-1A.kicad_sch]
2025-06-08 Renames driver
    [driver-12V-1A-inverting.kicad_sch]
2025-06-27 Adds simple buzzer script
    [buzzer.ino]
2025-06-27 Makes total script into a button-buzzer combination
2025-06-30 Adds electric circuit pics
2025-07-20 Fixes custom URI for ESP-Dash demo
    [webDash.ino]
2025-07-25 Adds separate standalone script for web authentication with ESP32AsyncWebserver
2025-07-28 Adds working script for pole PIR-sensors
2025-08-02 Fixes library regarding secrets includes
    [webAll.ino]
2025-11-30 Fixes platformio.ini for use with pioarduino
    [simple_tone.ino]
2025-12-06 Reads mp3 parms per sample
2025-12-13 Reassigns esp32 GPIO pins after leaving the PCB behind
2025-12-14 Has loudspeaker standalone script with esp32_wiring.h
2025-12-21 Has buzzer use the renamed esp2_wiring
    [buzzer.ino]
2025-12-22 Puts mp3 in separate library to ease standalone building in Arduino IDE
2025-12-24 Checks working state of dfplayer before soldering
2025-12-28 Updates stroboscope for wiring
2025-12-28 Updates simple_tone for esp32_wiring
2025-12-28 Updates loudspeaker script for esp32_wiring
2026-01-03 Adds drawing of esp32 pinout
2026-01-03 Adds DFPlayer to esp32 pinout drawing
2026-07-26 Adds some webserial print statements
2026-07-26 Adds KiCAD schema of head board
    [DFR0299.step, driver-12V-1A-inverting.kicad_sch, pole-electronics.kicad_pcb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]
2026-07-26 Cleans up KiCAD folder
    [DFR0299.step, pole-electronics.kicad_pcb, pole-electronics.kicad_sch]
